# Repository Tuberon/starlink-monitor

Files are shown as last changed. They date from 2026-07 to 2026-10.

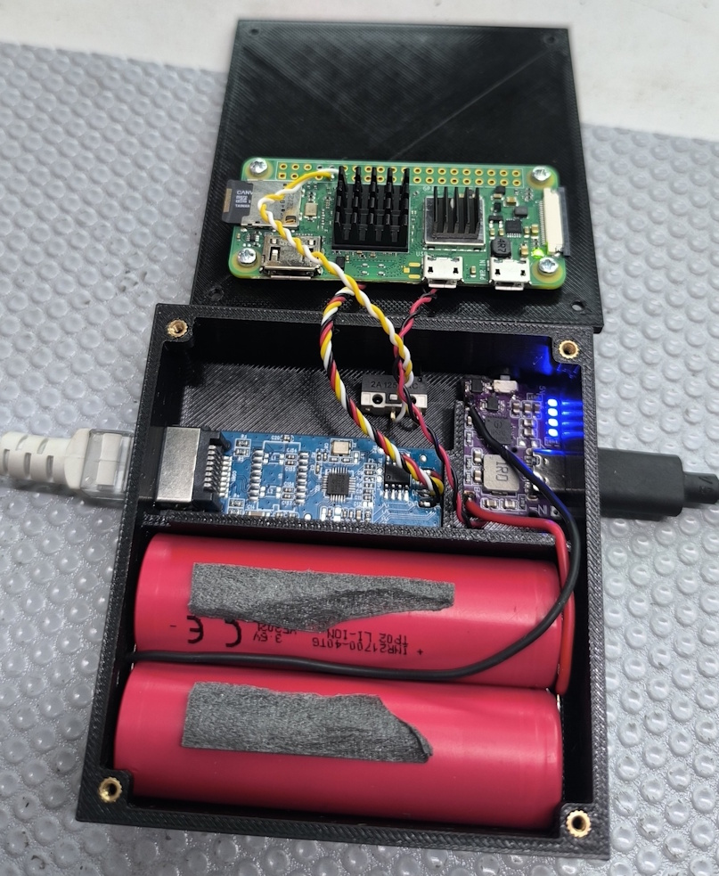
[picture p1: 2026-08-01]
dash_monitor.jpg

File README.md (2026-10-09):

# 🛰️ Starlink Mini Monitor & Watchdog — Raspberry Pi Zero 2 W

*Читати англійською: [README.en.md](README.en.md)*

Автономний монітор і watchdog для Starlink Mini на Raspberry Pi Zero 2 W.

**Зміст**: [Що робить](#-що-робить) · [Схема підключення](#-схема-підключення-опційне-обладнання) ·
[GPIO-кнопка](#-фізична-кнопка-виключення-gpio) ·
[LED активності](#-led-активності-sd-картки-gpio) ·
[TFT-дисплей](#️-фізичний-tft-дисплей-st7789-spi) ·
[Telegram](#-telegram-сповіщення-та-команди) · [Backup](#-backuprestore-налаштувань) ·
[healthz/PWA](#-додатково-healthz-pwa) · [Надійність](#️-надійність) ·
[Перевірка оновлень](#-про-ручну-перевірку-оновлень) · [Мережа](#-важливо-розуміти-про-мережу) · [Безпека](#-безпека) ·
[Навантаження](#-зниження-системного-навантаження-опційно-при-встановленні) ·
[Типізація](#-типізація-mypy) · [Тести](#-тести) ·
[Структура](#️-структура-проєкту) · [Встановлення](#-встановлення-та-оновлення) ·
[Конфігурація](#️-конфігурація) · [Залежності](#-залежності) · [Ліцензія](#-ліцензія)

## 📋 Що робить

1. Підключається до WiFi Starlink Mini як клієнт.
2. Опитує dish (`192.168.100.1:9200`, кожні 10с) і router
   (`192.168.1.1:9000`, кожні 35с) — Mini складається з ДВОХ логічних
   пристроїв в одному корпусі, кожен зі своєю прошивкою.
3. Auto-reboot усього Mini при watchdog-таймауті dish або готовому
   оновленні ПЗ (dish/router), зі спільним захистом від reboot-loop.
4. Збирає метрики Pi та історію Starlink в SQLite з автоочищенням.
5. Веб-дашборд (Flask): live-метрики, прошивки,
   WiFi-клієнти, останні 5 подій журналу, ручний reboot/перевірка
   оновлень. Сторінка `/stats` — повний журнал подій.
6. Telegram: сповіщення + команди `/status /checkupdates /reboot /id /help` (`/start` — те саме, що `/help`).
7. Reboot/shutdown Pi з веб-інтерфейсу або фізичної GPIO-кнопки,
   backup/restore всіх налаштувань одним файлом (опційно й у
   Telegram, автоматично чи вручну), `/healthz` для зовнішнього
   моніторингу, встановлюваний як PWA.
8. **Мультимовний інтерфейс** (українська/англійська) — перемикач на
   сторінці `/settings`, застосовується разом до веб-дашборду й
   Telegram-бота.

## 🔌 Схема підключення (опційне обладнання)

```
                    ┌──────────────────┐
                    │ TFT-дисплей 1.9" │
                    │ ST7789, SPI      │
                    └─────────┬────────┘
                              │ SPI: CS=GPIO8, DC=GPIO25,
                              │ RST=GPIO24, BL=GPIO18
                  ┌───────────┴───────────┐
                  │ Raspberry Pi Zero 2 W │
                  └─┬───────────────────┬─┘
           GPIO27 + │                   │ USB OTG-порт
           GND      │                   │ (єдиний, data)
           ┌────────┴────────┐  ┌───────┴───────┐
           │ Кнопка          │  │ USB-Ethernet  │
           │ вимк./підсвітка │  │ дротовий eth0 │
           └─────────────────┘  └───────────────┘

  (не показано: додатковий LED активності SD-картки — GPIO17 + GND,
   опційно, деталі нижче)
```

TFT-дисплей і кнопка — опційні (`STARLINK_DISPLAY_ENABLED=0` за
замовчуванням). USB-Ethernet теж опційний — WAN-failover fallback,
якщо є (докладніше — [Мережа](#-важливо-розуміти-про-мережу)).

## 🔘 Фізична кнопка виключення (GPIO)

Кнопка (нормально розімкнута) між обраним GPIO-піном (BCM) і GND,
внутрішній pull-up налаштовується сервісом. Увімкнено за замовчуванням
на `GPIO27` (`STARLINK_SHUTDOWN_BUTTON_PIN=27`); `0` вимикає, зміна
піна (за потреби) — у `/etc/starlink-monitor/env`:
```
STARLINK_SHUTDOWN_BUTTON_PIN=27
STARLINK_SHUTDOWN_BUTTON_HOLD_SEC=3
```
потім `sudo systemctl restart starlink-shutdown-button.service`.
Утримання довше заданого часу (типово 3с) → `systemctl poweroff`, з
подією в журналі й Telegram.

Якщо ввімкнено фізичний TFT-дисплей (`STARLINK_DISPLAY_ENABLED=1`) —
**та сама кнопка** отримує другу дію: **коротке** натискання
перемикає підсвітку дисплея, **довге** (як і раніше) вимикає Pi.
Обробляється тоді всередині `starlink-display.service`, а
`starlink-shutdown-button.service` сам себе вимикає (щоб не
конкурувати за той самий GPIO-пін). При reboot/poweroff (з кнопки чи
з веб-дашборду) — якщо дисплей увімкнено, на екрані на кілька секунд
з'являється повідомлення "Вимикається.../Перезавантажується..." перед
тим, як Pi реально почне вимикатись (`STARLINK_DISPLAY_SHUTDOWN_MESSAGE_DELAY_SEC`, типово 2с).

## 💡 LED активності SD-картки (GPIO)

Додатковий світлодіод, що коротко блимає при кожному реальному
записі в SQLite (dish-метрики, системні метрики, журнал подій,
статус router, автоматичний backup, VACUUM) — візуальна індикація
активності, аналогічна вбудованому activity-LED настільних дисків.
Вимкнено за замовчуванням (`STARLINK_ACTIVITY_LED_PIN=0`, той самий
принцип, що кнопка й дисплей — опційна периферія). Підключення: LED
(з резистором ~330Ω) між обраним GPIO-піном (BCM) і GND. Увімкнення —
у `/etc/starlink-monitor/env`:
```
STARLINK_ACTIVITY_LED_PIN=17
STARLINK_ACTIVITY_LED_BLINK_MS=50
```
потім `sudo systemctl restart starlink-monitor.service`. Обробляється
лише watchdog-процесом (не веб-дашбордом) — уникає конфлікту двох
процесів за один ексклюзивний GPIO-запит.

## 🖥️ Фізичний TFT-дисплей (ST7789, SPI)

Показує live-статус dish (online/offline, uptime, оновлення ПЗ,
версії прошивок). Вимкнено за замовчуванням (`STARLINK_DISPLAY_ENABLED=0`). Бібліотека — Adafruit CircuitPython ST7789.

> ⚠️ SPI зазвичай вимкнений: `sudo raspi-config nonint do_spi 0 &&
> sudo reboot` (`install.sh` попереджає, якщо ще не увімкнено).

Паспортна роздільна здатність — 170×320 (SKU MSP1901, portrait).
Піни залежать від підключення:
```
STARLINK_DISPLAY_ENABLED=1
STARLINK_DISPLAY_DC_PIN=25
STARLINK_DISPLAY_RST_PIN=24
STARLINK_DISPLAY_BL_PIN=18
STARLINK_DISPLAY_WIDTH=170
STARLINK_DISPLAY_HEIGHT=320
STARLINK_DISPLAY_ROTATION=0
STARLINK_DISPLAY_OFFSET_LEFT=35
```
потім `sudo systemctl restart starlink-display.service`. `BLK`
напряму до 3.3V — постав `BL_PIN=0`. `ROTATION`: `0/90/180/270`.
`OFFSET_LEFT=35` — емпіричне значення для цієї моделі (без зміщення —
кольоровий шум, підбирай кроком ~10-15px). Не міняй місцями WIDTH/HEIGHT.

Керування підсвіткою — та сама кнопка виключення (коротке=перемкнути,
довге=вимкнути Pi). Автовимкнення через `BACKLIGHT_AUTO_OFF_SEC`
(60с). При зміні статусу оновлення підсвітка блимає `UPDATE_FLASH_SEC`
(5с) — фізичне сповіщення без телефону.

## 💬 Telegram-сповіщення та команди

Налаштовуються на `/settings`:
1. Створіть бота через [@BotFather](https://t.me/BotFather), отримайте bot token.
2. Дізнайтесь chat_id через [@userinfobot](https://t.me/userinfobot).
3. Вставте token і chat_id (через кому — кілька отримувачів), "Зберегти",
   "Надіслати тестове", увімкніть перемикач.

> ⚠️ Bot token — у локальній SQLite (`settings`), у веб-інтерфейсі завжди замаскований.

**Команди** (лише для chat_id зі списку):
- `/status` — швидкий погляд: online, версія ПЗ, попередження
- `/checkupdates` — форсоване опитування dish/router, перевірка
  target-версій — та сама логіка, що кнопка на дашборді
- `/reboot` — підтвердження через inline-кнопки, 2 хв
- `/id [ID або частина]` — список тарілок або версії конкретної
- `/help` — список команд

Long polling (без webhook), у потоці `starlink-monitor.service`.

**Поведінка сповіщень:**
- `STARLINK_NOTIFY_PI_STARTUP=0` — вимикає сповіщення про реальний reboot Pi
- Тиша понад `STARLINK_NOTIFICATIONS_MUTE_AFTER` (15 хв) недоступності —
  відновлення повідомляється з тривалістю простою
- `STARLINK_NOTIFY_DISH_RECOVERY=0` — вимикає "✅ Dish знову online"
- Часті reboot групуються мовчки (`REBOOT_SPAM_THRESHOLD`/`_WINDOW_SEC`),
  підсумок після затишшя
- `STARLINK_MAX_LOGGED_FAILURES` (15) — журнал зупиняється, reboot триває
- Завжди приглушені: помилка перевірки роутера, "оновлення очікує", роумінг
- Не записуються й не показуються взагалі: попередження "карта перешкод
  скинута" (dish) і стан роутера "помилка завантаження оновлення" (тимчасова
  хмарна помилка SpaceX, роутер повторює сам)
- **Starlink вимкнено** (ніч, відключення світла): якщо не відповідає навіть
  роутер (3 опитування поспіль, ~30 с; коротші розриви WiFi ігноруються), watchdog не перезавантажує тарілку й не пише рядок на кожне
  опитування. Вранці — одне повідомлення "✅ Starlink знову доступний, був
  вимкнений N год" (лише якщо довше `NOTIFICATIONS_MUTE_AFTER`, 15 хв)
- Відкат прошивки (SpaceX інколи відкочує білди) — навмисно не
  сповіщається, `known_devices` оновлюється мовчки
- **Очікувані версії** (`/settings`) — кілька через кому, лише новіші приймаються

## 💾 Backup/restore налаштувань

На `/settings`: "Завантажити backup" — JSON з bot token, chat_id,
auto-reboot, очікуваними версіями прошивок, історією пристроїв і
перевизначеними параметрами моніторингу; "Відновити з backup" —
застосовує файл (історія пристроїв лише додається, не перезаписує наявне).

> ⚠️ Bot token у файлі — у відкритому вигляді, зберігай backup як secret.

**Відправка backup у Telegram** — автоматично періодично
(`STARLINK_TELEGRAM_BACKUP_ENABLED=1`, окремий інтервал
`_INTERVAL_HOURS`, типово тиждень) і/або вручну кнопкою "📨 Надіслати
backup у Telegram" (незалежно від автоматичного розкладу). Завжди
надсилає останній наявний файл, не створює новий — страховка на
випадок, якщо БД і backup лишаються на тій самій SD-картці.

## ➕ Додатково: healthz, PWA

- **`GET /healthz`** — для зовнішнього моніторингу (UptimeRobot тощо):
  БД доступна + watchdog реально опитує dish (свіжість метрик не старіша
  за 3 цикли опитування + інтервал пакетного запису
  `DISH_METRICS_BATCH_INTERVAL_SEC`, типово 60 с). `200 ok` / `503
  degraded`, нічого не пише в журнал — безпечно опитувати часто.
- **Встановлюваний дашборд (PWA)** — "Додати на головний екран" у
  Chrome/Edge. Service worker кешує лише статику (CSS/JS/іконки) —
  API-дані завжди наживо, service worker сам їх не кешує. Окремо:
  якщо Pi недосяжний з телефону (вийшов з WiFi-зони дії Pi) —
  дашборд показує останній відомий стан із браузерного `localStorage`
  та явним банером "останній відомий стан (X хв тому)", щоб не
  плутати із живими даними.
- **Темна/світла тема** — перемикач на `/settings`, зберігається між
  сесіями.
- **Мова інтерфейсу** — перемикач на `/settings` (українська/англійська),
  застосовується разом до веб-дашборду й Telegram-бота, включно з
  автоматичними сповіщеннями.

## 🛡️ Надійність

- **Watchdog для watchdog-а** — `starlink-monitor-healthcheck.timer`
  (раз/хв) опитує `/healthz`, примусовий restart при зависанні (не
  crash)
- **Менше записів на SD-картку** — dish-метрики batch-INSERT раз на
  `DISH_METRICS_BATCH_INTERVAL_SEC` (30с), не щоразу (зміна стану
  online/offline чи оновлення — одразу); graceful shutdown записує
  буфер перед завершенням; WAL-журнал SQLite не скидається на диск після
  кожного запису (у ~150 разів менше примусових синхронізацій), а
  налаштування синхронізуються одразу
- **ANALYZE + перевірка цілісності БД** — раз на добу (`VACUUM` — лише
  коли вільних сторінок ≥ 30%: він переписує всю БД); пошкодження →
  Telegram-сповіщення й аварійний backup
- **Автоматичний backup** — раз на тиждень, зберігає останні
  `AUTO_BACKUP_KEEP_COUNT` копій (типово 4)
- **Повторна спроба Telegram** — при мережевій помилці, `SEND_RETRIES`
- **Ротація журналу systemd** — `SystemMaxUse=200M`

## 🔄 Про ручну перевірку оновлень

Кнопка "Перевірити стан оновлень" форсує негайне локальне опитування
dish/router. Локальний gRPC API не має команди "перевір оновлення в
хмарі SpaceX" (це робить хмарний бекенд офіційного застосунку) —
`software_update` повертає `FailedPrecondition`/`Unimplemented`, тож
кнопка робить максимум технічно можливого.

## 🌐 Важливо розуміти про мережу

Starlink Mini роздає власний WiFi. RPi Zero 2 W має один WiFi-модуль,
тож для одночасного доступу до Starlink і звичайного інтернету
потрібен USB-Ethernet (рекомендовано) або лише Starlink WiFi
(моніторинг і reboot dish не залежать від зовнішнього інтернету).

При USB-Ethernet `install.sh` пропонує (лише при першому
встановленні) статичні IP для обох інтерфейсів — DHCP на обох може
спричиняти конфлікти маршрутів. На WiFi-профілі Starlink також
вимикається IPv6: коли Starlink без інтернету, системні DNS/HTTPS-
запити інакше йдуть через мертвий IPv6-маршрут замість робочого
IPv4 через `eth0`. На вже встановленій системі (мережевий блок не
повторюється при оновленні) — вручну:
`sudo nmcli connection modify "<WiFi-профіль>" ipv6.method disabled`.

**WAN-failover**: `starlink-wan-failover.timer` (~30с) перевіряє
реальний вихід в інтернет через `wlan0`; коли Starlink недоступний —
`nmcli` знижує пріоритет `wlan0`, `eth0` стає дефолтним для всієї
системи. Маршрути до dish/router не зачіпаються. Telegram-запити
мають додатковий, власний fallback (`SO_BINDTODEVICE` на `eth0` +
ручна DNS-резолюція за потреби) — працює незалежно, без
налаштування.

## 🔒 Безпека

- **Веб-інтерфейс без автентифікації** (порт `8080`,
  `STARLINK_WEBUI_HOST=0.0.0.0`) — свідоме рішення для довіреної
  локальної мережі. Не відкривайте порт в інтернет (port forwarding,
  публічні тунелі): хто бачить дашборд, може перезавантажити тарілку й
  вимкнути Pi.
- **Захист від міжсайтових запитів**: POST із чужого сайту (за
  заголовками `Origin` і `Sec-Fetch-Site`, які браузер виставляє сам)
  відхиляється з кодом 403; `curl` і скрипти без цих заголовків
  працюють. Не закрито DNS-rebinding (запит із чужого імені, що
  резолвиться в IP станції).
- **Привілеї**: сервіси працюють від непривілейованого користувача;
  `sudo` дозволяє йому рівно чотири команди (`systemctl restart` двох
  сервісів, `reboot`, `poweroff`). Лише healthcheck і WAN-failover
  працюють від root, і скрипти, які вони виконують, належать root.
- **Секрети**: токен Telegram — у `env`-файлі (права 600) і в БД
  (каталог даних 700); у логах він автоматично маскується. **Backup
  містить токен** — зберігайте його як секрет.

## 📉 Зниження системного навантаження (опційно, при встановленні)

`install.sh` (лише при першому встановленні) пропонує вимкнути
непотрібні для headless-моніторингу служби: `bluetooth`/`hciuart`,
`avahi-daemon` (mDNS), `triggerhappy`, `ModemManager` — перевіряє
кожну індивідуально (лише реально активні), вимикає (не видаляє,
легко повернути `systemctl enable --now`).

**Обережно з `avahi-daemon`**: вимикання забере доступ через
`raspberrypi.local` (не по IP) — скрипт попереджає, якщо активна.

Мережеві служби (`ssh`, `NetworkManager`, `dhcpcd`) ніколи не
пропонуються — headless-пристрій без фізичного доступу не можна
ризикувати заблокувати від SSH. Окремо — `apt-get autoremove`/`clean`.

Натомість `install.sh` вмикає `fstrim.timer` (періодичний TRIM для
SD-картки; якщо картка його не підтримує — нічого не робить, не
шкодить).

## 🔍 Типізація (mypy)

Увесь код проєкту (крім `app/vendor/` — сторонній код) типізований і
проходить `mypy` у **суворому режимі** (`app/*` — еквівалент `--strict`,
прапорці в `mypy.ini`; у `tests/` типізація м'яка). Виклики `requests`,
`psutil`, `dns` перевіряються справжніми стабами (`types-*` у
`requirements-dev.txt`); ігнорування імпортів дозволено лише для
апаратних бібліотек Pi — суворість тримає тест
`test_mypy_config_stays_strict`. Результат `mypy` залежить від
встановлених пакетів (без Flask — понад 30 помилок, усі в `webapp.py`),
тож запускати у повному dev-середовищі. Перевірка перед
комітом/оновленням:
```bash
pip install -r requirements-dev.txt
mypy app/
ruff check .
```
`ruff check` — перевірка коду (невикористане, типові пастки, безпека;
правила в `ruff.toml`), також виконується як один із тестів. Не
автоформатування: `ruff format` свідомо не використовується. Без CI — для одноосібного hobby-проєкту такого
масштабу пропорційніше запускати локально як ще одну живу перевірку
поруч із `py_compile`, ніж інвестувати в повноцінну CI-інфраструктуру
(деталі рішення — `docs/decisions-log.md`).

## ✅ Тести

1116 тестів (`pytest-randomly` — стійкість до порядку виконання), 27
файли у `tests/`. Крім stateful-логіки (групування reboot-спаму,
дедублікація сповіщень про target-версії прошивки, компаратор версій,
eth0-fallback для Telegram) — і hardware-залежний код (GPIO/SPI-
дисплей, кнопка виключення) тестується підміною `sys.modules` для
`gpiod`/`board`/`digitalio`/`busio`/`adafruit_rgb_display` ще до
виклику функції (ці бібліотеки самі імпортуються лише всередині
функцій, не на рівні модуля). Кожен тест автоматично отримує
тимчасові БД, файл налаштувань і теку бекапів (`tests/conftest.py`) —
робочих `/etc/starlink-monitor` і `/var/lib/starlink-monitor` тести не
торкаються. Перевірка (на машині розробки):
```bash
pip install -r requirements.txt -r requirements-dev.txt
pytest
```
Покриття по модулях: `pytest --cov=app --cov-report=term-missing`.

Тести власності root (`test_install_security.py`) виконуються лише від
root і пропускаються для звичайного користувача.

**На самому Pi** — в окремому середовищі (не в робочому `/opt/.../venv`,
без `--break-system-packages`) і без бібліотек заліза (`adafruit-*`), щоб
жоден тест не торкнувся справжніх GPIO/SPI. Сервіси можуть працювати:
```bash
cd ~/starlink-monitor            # розпакований архів
python3 -m venv ~/dw-dev
grep -vi adafruit requirements.txt > /tmp/req-tests.txt
~/dw-dev/bin/pip install -r /tmp/req-tests.txt -r requirements-dev.txt
~/dw-dev/bin/mypy app/ && ~/dw-dev/bin/ruff check . && ~/dw-dev/bin/pytest
```

## 🗂️ Структура проєкту

```
starlink-monitor/
├── app/            # Python: моніторинг, Flask, Telegram, GPIO, дисплей, i18n
├── templates/      # HTML (index, settings, stats)
├── static/         # JS/CSS/іконки
├── tests/          # 1116 тестів (27 файлів), pytest-randomly
├── systemd/        # unit-файли сервісів
├── scripts/        # install/update/uninstall + системні перевірки
├── docs/           # architecture.md, index.md (повний опис кожного файлу), decisions-log.md, plan.md
├── requirements.txt      # production-залежності (прямі, точні піни)
├── constraints.txt       # закріплені ТРАНЗИТИВНІ версії (pip install -c)
├── requirements-dev.txt  # mypy/pytest/ruff/pip-audit/hypothesis
├── mypy.ini              # mypy: суворий режим для app/*
├── pytest.ini            # налаштування pytest
├── ruff.toml             # ruff: правила F, B, E9, PLE, S
└── LICENSE               # MIT
```

Детальний опис кожного файлу — [`docs/index.md`](docs/index.md).

## 📦 Встановлення та оновлення

**📥 Перше встановлення:**
```bash
tar -xzf starlink-monitor.tar.gz && cd starlink-monitor
sudo bash scripts/install.sh
```
Ставить системні пакети, `grpcurl`, Python venv, sudo-права,
systemd-сервіси; наприкінці — опційний запит статичних IP і опційне
вимкнення непотрібних для headless-моніторингу системних служб
(лише при першому встановленні, див. секції вище — "Важливо
розуміти про мережу" й "Зниження системного навантаження").

**🔁 Оновлення** (архів у домашньому каталозі, напр. через `scp`):
```bash
sudo bash /opt/starlink-monitor/scripts/update.sh
```
Розпаковує й викликає `install.sh` в update-режимі: системні пакети
не чіпаються, синхронізуються лише змінені файли, мережевий запит не
повторюється. SHA-256 запобігає повторному встановленню того самого
архіву; шлях можна вказати аргументом.

Після установки каталог `/opt/starlink-monitor` і `scripts/` належать
root: їх виконує root (юніти healthcheck і WAN-failover та `update.sh`
під `sudo`), тож непривілейований користувач сервісів не може їх
підмінити. Редагувати їх вручну — через `sudo`; `app/` і `venv`
лишаються за користувачем сервісів.

**✅ Після встановлення:**
1. `sudo nmcli device wifi connect "<SSID>" password "<пароль>" ifname wlan0`
2. Дашборд: `http://<ip-пристрою>:8080`

**🗑️ Повне видалення:**
```bash
sudo bash /opt/starlink-monitor/scripts/uninstall.sh
```
Зупиняє сервіси, видаляє код і sudoers-правило. Історію метрик і
Telegram-налаштування видаляє лише після окремого підтвердження — за
замовчуванням лишаються для повторного встановлення.

## ⚙️ Конфігурація

Редагується на сторінці `/settings` (панель "Параметри моніторингу",
53 параметри згруповані за категоріями: моніторинг/надійність/
Telegram/GPIO) або вручну в `/etc/starlink-monitor/env`. Повний
список з коментарями — у `app/config.py`.

3 параметри навмисно недоступні через `/settings` (лише ручне
редагування `.env`-файлу) — `STARLINK_DB_PATH` (зміна шляху до БД
без міграції даних), `STARLINK_WEBUI_HOST` (self-lockout — можна
відрізати себе від `/settings`, змінивши адресу прослуховування) і
`STARLINK_AUTO_BACKUP_DIR` (дефолт обчислюється поруч із БД).

`/settings` перевіряє не лише тип, а й допустимий діапазон кожного числового
параметра: відхиляє `nan`/`inf`, від'ємні значення та `0` для таймерів (там `0`
означав би «на кожній ітерації», а не «вимкнено»); нуль лишено лише там, де він
справді означає «вимкнено» (піни, автовимкнення підсвітки). Адреси `STARLINK_DISH_ADDR`/`STARLINK_ROUTER_ADDR` приймаються лише як
`host:порт` (порт 1–65535). Ручне редагування `env`-файлу межі не перевіряє, але й не валить сервіси: некоректне значення (порожнє, `abc`) замінюється типовим із попередженням у журналі; булеві приймають `1/true/yes/on` і `0/false/no/off`.

Найважливіші для першого налаштування:

| Змінна | За замовчуванням | Опис |
|---|---|---|
| `STARLINK_DISH_ADDR` | `192.168.100.1:9200` | адреса тарілки |
| `STARLINK_ROUTER_ADDR` | `192.168.1.1:9000` | адреса роутерного компонента Mini |
| `STARLINK_WEBUI_PORT` | `8080` | порт веб-інтерфейсу |
| `STARLINK_HISTORY_DAYS` | `14` | скільки днів зберігати історію метрик/подій |
| `STARLINK_MAX_FAILURES` | `6` | скільки невдалих опитувань перед watchdog-reboot |

GPIO-піни опційних фіч (кнопка/LED/дисплей) — див. відповідні секції
вище, кожна опційна фіча описана окремо з power-схемою.

Параметри читаються один раз при старті процесів — після збереження
на `/settings` натисни "Зберегти й перезапустити сервіси" (кнопка
поруч), або вручну:
```bash
sudo systemctl restart starlink-monitor.service starlink-webui.service
```

## 🧩 Залежності

`requirements.txt` закріплює прямі пакети, `constraints.txt` —
транзитивні (`install.sh` ставить `pip install -r requirements.txt -c
constraints.txt`; без цього pip ніколи не оновлював уже встановлені,
зокрема системні, версії). Апаратні `adafruit-*` свідомо не закріплені.
Аудит вразливостей: `pip install pip-audit && scripts/audit_deps.sh`.

**Vendored `starlink_grpc.py`.** Походження зафіксовано в
`app/vendor/PROVENANCE` (upstream-коміт, дата, sha256; тест звіряє їх з
файлом). Оновлення до найновішої upstream-версії — опційно,
`scripts/fetch_starlink_grpc.sh` (завантаження у тимчасовий файл,
перевірки, резервна копія `.prev`, атомарна заміна; `--commit=<sha>` —
конкретна ревізія; `--wait-for-dish` — чекати доступності тарілки;
`--restart-services` — перезапустити сервіси після успіху).

## 📄 Ліцензія

© 2026 JunioR. Розповсюджується під ліцензією MIT — див. файл
[`LICENSE`](./LICENSE).

Проєкт включає (vendored, `app/vendor/starlink_grpc.py`) файл зі
стороннього репозиторію
[sparky8512/starlink-grpc-tools](https://github.com/sparky8512/starlink-grpc-tools)
для відтворюваності збірки (не завантажується динамічно при
встановленні) — **його ліцензійні умови визначає власний автор**, окремо
від MIT цього репозиторію (Unlicense — суспільне надбання). Походження й
оновлення — у розділі «Залежності».

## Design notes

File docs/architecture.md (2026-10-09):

# Архітектура: Starlink Mini Monitor & Watchdog

## Призначення

Моніторинг і автоматичне обслуговування Starlink Mini через Raspberry
Pi Zero 2 W: веб-дашборд, watchdog з авто-reboot, Telegram-сповіщення
й вхідні команди.

## Фізична топологія

Starlink Mini = **два логічні пристрої в одному корпусі**, кожен зі
своєю прошивкою:
- **dish** (тарілка): `192.168.100.1:9200`, gRPC через `starlink_grpc.py`
- **router** (WiFi-роутер): `192.168.1.1:9000`, gRPC через `grpcurl` subprocess

Це підтверджено живими викликами (`grpcurl describe`) під час
розробки — обидва мають окремі `DeviceInfo`, окремі стани оновлення
ПЗ (`SoftwareUpdateState` для dish, `WifiSoftwareUpdateState` для
router — різні enum з різними назвами станів).

## Модулі (app/)

| Файл | Відповідальність |
|---|---|
| `starlink_client.py` | gRPC-клієнт: статус dish/router, reboot_dish(); vendored gRPC-стек вантажиться ліниво (`_grpc_module()`) |
| `monitor.py` | Watchdog: цикл опитування (періодичні задачі `_Periodic`), авто-reboot, логування подій, запуск Telegram-бота (точка входу) |
| `services.py` | Спільна логіка для monitor/webapp/telegram_bot: відстеження версій прошивок (`check_updates_now`, `upsert_*`), бекапи (`perform_auto_backup` з ротацією), перевірка цілісності БД |
| `webapp.py` | Flask, REST API (довідник нижче), роздає `/`, `/settings`, `/stats`, `/healthz`; відхиляє POST із чужого сайту (CSRF), у JSON немає `Infinity`/`NaN` |
| `db.py` | SQLite: metrics, events, system_metrics, router_status, known_devices, settings; атомарні "прочитати → вирішити → записати" (`claim_setting`, `BEGIN IMMEDIATE`), "останній" запис ігнорує рядки з майбутнього |
| `i18n.py` | Мультимовний інтерфейс (uk/en): словник перекладів, `t()`, мова з settings |
| `telegram_notify.py` | Вихідні сповіщення (повторна спроба, eth0-fallback; токен не потрапляє в логи) |
| `log_redact.py` | Маскування токена бота в текстах помилок і логах (`redact()`, `RedactingFilter`) |
| `telegram_bot.py` | Вхідні команди `/status`, `/checkupdates`, `/reboot`, `/id`, `/help` (`/start` = `/help`); обробка кожного update у пулі потоків, не блокує polling |
| `atomic_io.py` | Атомарний запис файлів (temp → fsync → replace): env зі /settings і автобекапи не обнуляються до запису |
| `labels.py` | Спільні таблиці "код -> ключ перекладу" для станів оновлення й alert-прапорців (monitor.py + telegram_bot.py, без дублювання; `_label()` перекладає лише потрібний код) |
| `system_metrics.py` | Метрики Pi (CPU/RAM/диск/температура) |
| `shutdown_button.py` | Фізична кнопка виключення через GPIO (окремий процес) |
| `pi_power.py` | Спільний reboot/poweroff для webapp.py/shutdown_button.py, DB-сигнал для повідомлення на дисплеї |
| `activity_led.py` | Опційний LED активності SD-картки - блимає при кожному commit у БД (не окремий процес, частина monitor.py) |
| `display.py` | Фізичний TFT-дисплей статусу (ST7789, SPI, окремий процес) |
| `gpio_utils.py` | Спільна gpiod v1/v2-сумісна логіка читання GPIO-входу (shutdown_button.py + display.py) і запису GPIO-виходу (activity_led.py) |
| `config.py` | Конфігурація, env-змінні |
| `config_editor.py` | Читання, валідація (таблиця `_VALIDATORS`, межі `LIMITS`, формат адрес) і атомарний запис `/etc/starlink-monitor/env` через `/settings` |

`app/vendor/starlink_grpc.py` — **vendored** (фізично включений в архів
проєкту, не в таблиці вище, бо не наш код) файл зі стороннього
репозиторію sparky8512/starlink-grpc-tools, для відтворюваності
збірки: install.sh НЕ завантажує його динамічно з інтернету; `starlink-grpc-fetch.service` встановлюється, але НЕ вмикається автоматично (опційне ручне оновлення до найновішої upstream-версії).
`starlink_client.py` вантажить його ЛЕДАЧЕ — `_grpc_module()` при
першому зверненні до тарілки (не при імпорті модуля): gRPC + protobuf +
`yagrc` + vendored файл — це ~13 МБ RSS і ~50 мс, а веб-процес імпортує
клієнта лише заради двох кнопок. Імпорт іде через `from app.vendor
import starlink_grpc` у `try/except Exception` (не лише ImportError:
обірваний файл дає `SyntaxError`, відсутній `yagrc` —
`ModuleNotFoundError`), під блокуванням (потоки монітора,
бота й веб-запитів не імпортують і не логують помилку кожен окремо).
Недоступний модуль → `starlink_grpc = None`, а `get_status()` віддає
`DishStatus(online=False, local_fault=True, error="starlink_grpc module
missing (<причина>)")`. Тести підміняють глобальну `starlink_grpc`
напряму; початкове значення — маркер `_UNLOADED`.

**`local_fault`** — помилка НАШОЇ сторони, не тарілки. Без цієї позначки
watchdog вважав тарілку зависшою й перезавантажував її кожні
`MIN_REBOOT_INTERVAL` (симуляція: 22 рази за 67 хв) — тобто пошкоджений
локальний файл відключав би інтернет; колишній опис "код і далі коректно
працює" був неправдою. Тепер `poll_once()` при `local_fault` не рахує збій, не
перезавантажує тарілку й повідомляє РАЗ за процес (подія `local_fault`, лог,
Telegram); усунення потребує відновлення файлу й перезапуску сервісу (модуль
завантажується при старті).

**Походження й оновлення.** `app/vendor/PROVENANCE` фіксує upstream-коміт
(зараз `8f34f4cd…`, 2026-03-20; знайдено порівнянням sha256 з усією історією
файлу — збіг побайтовий), дату, sha256 і ліцензію (Unlicense); тест звіряє
sha256 із файлом. `scripts/fetch_starlink_grpc.sh` тепер: завантаження у
тимчасовий файл → перевірки (розмір ≥ 20 КБ, синтаксис Python, наявність
`ChannelContext` і `get_status` — те, що використовує наш клієнт) →
резервна копія `starlink_grpc.py.prev` → атомарна заміна → запис
`PROVENANCE`. Завантаження — за незмінним URL з SHA коміту (з Atom-стрічки
комітів; `--commit=<sha>` задає ревізію явно), а не з рухомої гілки `main`.

**Залежності.** `requirements.txt` — прямі точні піни, `constraints.txt` —
закріплені транзитивні (12 пакетів, складено у чистому venv; урахований
`grpcio-reflection` від `yagrc`). `install.sh` ставить `pip install -r
requirements.txt -c constraints.txt` і вважає залежності зміненими, якщо
різняться requirements.txt АБО constraints.txt. Constraints лише обмежують
версії й не додають імен, тому не викликають "суттєвої зміни" (повного
перевстановлення); апаратні `adafruit-*` не зачіпаються. Причина: `pip`
вважає вже встановлені (зокрема системні, через `--system-site-packages`)
версії задоволеними, тож на Pi транзитивні пакети (urllib3 2.6.3, idna 3.11
з advisory) не оновлювались ніколи. Аудит: `scripts/audit_deps.sh`.

## Автоматичний reboot dish/router — умови спрацювання

1. **Watchdog**: dish не відповідає N опитувань поспіль
2. **Update-ready dish**: `update_state == "REBOOT_REQUIRED"`
3. **Update-ready router**: `update_state == "REBOOT_PENDING"`

Усі три через `db.get_auto_reboot_enabled()` (runtime, перемикається
з веб-інтерфейсу без перезапуску сервісу) і захищені
`MIN_REBOOT_INTERVAL_SEC` (180с) від reboot-loop.

`Watchdog.first_failure_ts` відслідковує тривалість безперервної
недоступності dish. Якщо вона перевищує `NOTIFICATIONS_MUTE_AFTER_SEC`
(900с) — Telegram-сповіщення про watchdog auto-reboot придушуються
(`db.insert_event` не зачіпається, лише `_notify`); відновлення
зв'язку повідомляється (`✅ Dish знову online...`), якщо
`NOTIFY_DISH_RECOVERY=1` (дефолт, `0` вимикає — journal-лог
(`logger.info`) і далі пишеться незалежно від цього параметра,
лише Telegram-сповіщення пригнічується; знайдено запитом
користувача — короткі flap-відновлення не завжди інформативні).

**Starlink вимкнено** (`_enter_starlink_offline()`/`_exit_starlink_offline()`): коли dish не відповідає, `poll_once()` перевіряє TCP-
з'єднання з gRPC-портом роутера (`StarlinkClient.router_reachable()`,
2 с; без WiFi Starlink пакети йдуть маршрутом за замовчуванням через
eth0 і чекають повний timeout). Роутер
теж мовчить — це вимкнений Starlink (ніч, відключення світла), а не
зависання тарілки: reboot не шлеться (команда йде тим самим
недоступним шляхом), `consecutive_failures` не росте, рядок на кожне
опитування не пишеться — лише подія `starlink_offline` на вхід і
`starlink_online` на вихід. Telegram — одне повідомлення при поверненні,
якщо Starlink був вимкнений довше `NOTIFICATIONS_MUTE_AFTER_SEC`
(хвилинні перезавантаження при оновленні прошивки мовчать — вони мають
власні сповіщення). Роутер відповідає, dish ні — звичайний watchdog.
Виявлено на реальній ночі користувача: 9+ год вимкненого Starlink
давали ~114 марних спроб reboot і ~5900 рядків журналу. `"Пропускаю
авто-reboot"` пишеться один раз на вікно очікування
(`_reboot_skip_logged_for`), не щоопитування. Гістерезис: стан
фіксується, лише коли роутер мовчить `STARLINK_OFFLINE_CONFIRM_POLLS`
(3) опитувань поспіль; тривалість рахується від першого збою. Без
цього щохвилинні пів-секундні розриви WiFi на Pi користувача, що
інколи збігаються з опитуванням, давали до ~100 подій на годину.

**Групування reboot-спаму** (`_notify_reboot()`/`_check_reboot_spam_recovery()`) — інша ситуація, ніж `NOTIFICATIONS_MUTE_AFTER_SEC`: та
працює за ТРИВАЛІСТЮ однієї безперервної відмови, це — за ЧАСТОТОЮ
окремих коротких reboot-циклів (флап), кожен з яких минає
`MIN_REBOOT_INTERVAL_SEC` і тому НЕ приглушується першим механізмом.
`Watchdog.reboot_notify_ts` — ковзний список timestamps уже
надісланих reboot-сповіщень (не всіх спроб reboot, лише тих, що
дійшли до Telegram); коли їх назбирається `REBOOT_SPAM_THRESHOLD`+ за
`REBOOT_SPAM_WINDOW_SEC` — подальші мовчки рахуються (`muted_reboot_count`), **без окремого повідомлення про початок групування** (щоб
не додавати ще одне сповіщення до вже частих — навмисно прибрано за
запитом користувача), до затишшя (`_check_reboot_spam_recovery()`,
викликається щоцикл на початку `poll_once()`), тоді підсумок і
повний скид стану. Застосовано лише до **успішних** reboot-
сповіщень (`🔁`) — невдалі (`❌`) лишаються без групування, рідкісніші
й важливіші показувати щоразу.

## systemd-сервіси

| Сервіс | Роль | Особливості безпеки |
|---|---|---|
| `starlink-monitor.service` | Watchdog + Telegram-бот (потік) | `NoNewPrivileges=true`, `AmbientCapabilities=CAP_NET_RAW` (SO_BINDTODEVICE), `CapabilityBoundingSet` звужено до цієї capability |
| `starlink-webui.service` | Flask dashboard | БЕЗ `NoNewPrivileges` (потрібен sudo для reboot/poweroff Pi), `AmbientCapabilities=CAP_NET_RAW`, `CapabilityBoundingSet` НЕ звужено (sudo systemctl reboot успадкував би обмеження) |
| `starlink-shutdown-button.service` | Слухає GPIO-кнопку виключення | БЕЗ `NoNewPrivileges` (sudo poweroff), `Restart=on-failure` (не `always` — чистий вихід при вимкненій кнопці не збій) |
| `starlink-grpc-fetch.service` | Опційне ручне оновлення vendored `starlink_grpc.py` до найновішої upstream-версії — НЕ enabled/started автоматично (файл vendored, `app/vendor/`) | — |
| `starlink-wan-failover.service`/`.timer` | Періодична (кожні ~30с) перевірка інтернету через wlan0, коригування route-metric | root-сервіс; `CapabilityBoundingSet=CAP_NET_ADMIN CAP_NET_RAW` — навіть root тут без решти системних можливостей |
| `starlink-monitor-healthcheck.service`/`.timer` | Раз/хв опитує `/healthz`, force-restart `starlink-monitor.service` при не-200 (deadlock/livelock, не crash — `Restart=always` цього не бачить) | root-сервіс (потрібен для `systemctl restart` іншого юніта); `NoNewPrivileges=true`, `ProtectSystem=strict` |
| `starlink-display.service` | Фізичний TFT-дисплей (ST7789, SPI), вимкнено за замовчуванням | `SupplementaryGroups=gpio spi`; БЕЗ `NoNewPrivileges` (кнопка виключення обробляється тут же, потребує `sudo poweroff` — реальний баг був знайдений і виправлений: старий коментар помилково лишав `NoNewPrivileges=true` вже після того, як обробку кнопки перенесли сюди) |

`ProtectSystem=strict` на всіх — файлова система read-only, крім явно
дозволених шляхів.

## Встановлення / оновлення

- `scripts/install.sh` — детектує install vs update режим
  (`/opt/starlink-monitor` існує чи ні). У update-режимі: пропускає
  apt/pip якщо `requirements.txt` не змінився; **виявляє суттєві
  зміни** (нові пакети — не просто зміна версії) і при виявленні
  повністю видаляє й перевстановлює. Наприкінці, **лише в install-режимі** —
  опційний інтерактивний блок налаштування статичних IP для eth0/wlan0
  (з підтвердженням, дефолти редаговані), вимикає конфліктуючий `dhcpcd`.

  **Зниження системного навантаження** (теж лише install-режим, після
  мережевого блоку) — інтерактивна пропозиція `systemctl disable --now`
  для короткого, добре перевіреного списку служб (`bluetooth`,
  `hciuart`, `avahi-daemon`(+`.socket`), `triggerhappy`, `ModemManager`).
  Кожен кандидат перевіряється **індивідуально** через `systemctl
  list-unit-files`+`is-enabled`/`is-active` **перед** пропозицією — не
  питає про службу, якої немає в системі (мінімальні образи вже можуть
  бракувати частини списку). **Вимикає, не видаляє** пакети — уникає
  ризику зламаних залежностей через `apt purge`, легко відновлюється
  через `systemctl enable --now`. Явне попередження про `avahi-daemon`
  (`.local`-mDNS-резолюція), якщо він серед виявлених кандидатів —
  вимкнення могло б забрати доступ через `raspberrypi.local` для тих,
  хто підключається так, не по IP. Мережеві служби (`ssh`,
  `NetworkManager`, `wpa_supplicant`, `dhcpcd`) і core systemd-юніти
  **ніколи не входять у список кандидатів** — на headless-пристрої без
  фізичного доступу заблокований SSH означає повну втрату контролю.
  Окремий, незалежний крок (той самий блок) — опційний `apt-get
  autoremove`/`clean` (дисковий простір, не RAM/CPU).
- `scripts/update.sh` — ручне оновлення: sha256-перевірка архіву,
  розпакування, виклик install.sh.
- `scripts/uninstall.sh` — зупиняє й видаляє сервіси, sudoers-правило,
  код (`/opt/starlink-monitor`). БД (`/var/lib/starlink-monitor`) і
  env-конфіг (`/etc/starlink-monitor`) видаляються лише після окремого
  підтвердження — за замовчуванням лишаються для повторного встановлення.

## База даних (SQLite, /var/lib/starlink-monitor/history.db)

WAL journal_mode — паралельне читання (webui) і запис (monitor) без блокувань.
`synchronous=NORMAL` (не дефолтний `FULL`) — офіційно рекомендований
режим для WAL: `fsync()` лише при checkpoint, не на кожному commit,
суттєво менше фізичних записів на SD-картку при опитуванні кожні
~10с. Ризик — втрата лише кількох останніх транзакцій при раптовому
знеструмленні (БД не пошкоджується, це гарантує WAL сам по собі).

- `metrics` — історія опитувань dish (latency, dish_id, update_state, ...)
- `events` — журнал подій (reboot, зміни стану, попередження, підключення
  нової тарілки). Повтори того самого `kind`+`message` підряд стискаються
  в один рядок (`count` замість нового запису щоразу)
- `system_metrics` — CPU/RAM/диск/температура Pi
- `router_status` — останній відомий стан роутера, включно зі списком
  під'єднаних WiFi-клієнтів (`clients`: ім'я/MAC, IP, діапазон, сигнал,
  час у мережі)
- `settings` — runtime key-value (auto_reboot_enabled, telegram config,
  dish_target_version/router_target_version + їхні
  `*_notified` пари — див. нижче)

**Write-only колонки, залишені в схемі без запису** (аудит показав, що
ніколи не читаються: `metrics.currently_obstructed` дублює
`obstruction_fraction`, `router_status.bootcount` ніколи не
відображався, `events.last_ts` дублював `ts` в одному й тому самому
UPDATE): значення `NULL` для нових рядків, старі рядки не чіпались;
`starlink_client` ці два поля відповіді Starlink більше й не розбирає.
Схема НЕ змінена (без `DROP COLUMN`) — менший ризик для вже існуючих БД
на реальних пристроях, ніж міграція.
- `known_devices` — по одному рядку на dish_id: версії ПЗ dish/router
  і час останньої зміни кожної. Джерело для `/id <dish_id>` у Telegram-боті.
  `upsert_known_device_dish()`/`upsert_known_device_router()` повертають
  `(real_change, old_version)` — `real_change=True` лише коли версія
  реально відрізняється від РАНІШЕ ВІДОМОГО значення (не `None`, не
  перше знайомство з пристроєм/полем), і завжди оновлюють `known_devices` реальною поточною версією незалежно від напрямку зміни.
  `services.upsert_dish_and_notify()`/`upsert_router_and_notify()`
  сповіщають лише про реальне ОНОВЛЕННЯ (`format_firmware_change_message()`,
  використовує `db.is_older_version()` — той самий
  толерантний компаратор, що для target-версій): "🔄 Прошивка X
  оновлена: X → Y" для forward-змін. Якщо нова версія СТАРІША за
  попередню (SpaceX інколи відкочує прошивку глобально) - навмисно
  НЕ сповіщає (`format_firmware_change_message()` повертає `None`,
  обидва виклики перевіряють на `None` перед `notify_fn(...)`) - за
  запитом користувача, `known_devices` все одно оновлюється мовчки.
  Спільний для dish і router (та сама функція).

`Watchdog._log_alerts_change()` журналює появу/зникнення кожного dish-
alert'а окремою подією в БД (`dish_alert`/`dish_alert_resolved`).
Виняток: `obstruction_map_reset` при ЗНИКНЕННІ (`resolved`) навмисно
пропускається повністю — Starlink періодично скидає карту перешкод
сам по собі як частину нормальної роботи (не аварійна подія), тому
"Попередження знято: карта перешкод скинута" не журналюється взагалі.
Точковий фільтр лише для цього одного alert'а й лише для `resolved`-
напрямку — при появі (`appeared`) той самий alert усе ще журналюється
й потрапляє в Telegram (не в `MUTED_DISH_ALERTS`), лише завершення
цього конкретного, нормального циклу не варте окремого запису.

**"🟢 Dish Watch запущено (Raspberry Pi перезавантажено)"** —
`monitor.pi_just_booted()` (чиста, тестована функція, порівнює
`psutil.boot_time()` з `time.time()`, поріг 120с) відрізняє РЕАЛЬНЕ
завантаження Pi від звичайного `sudo systemctl restart starlink-monitor.service` (напр. під час `update.sh`) — без цього сповіщало б
набагато частіше, ніж "Pi увімкнувся/перезавантажився". Викликається
на початку `run_forever()`, одразу після `db.init_db()`, ПЕРЕД
`telegram_bot.start()` (не залежить від нього — `telegram_notify.send_message()` окремий, самостійний модуль). `NOTIFY_PI_STARTUP=0`
(дефолт `1`) вимикає повністю.

## Буферизація dish-метрик (SD-card-wear reduction)

`Watchdog.metrics_buffer` — dish-зчитування (кожні `POLL_INTERVAL_SEC`,
типово 10с) накопичуються в пам'яті замість негайного окремого
запису. `flush_metrics_buffer()` викликає `db.insert_metrics_batch()`
(одна транзакція, `executemany`) раз на `DISH_METRICS_BATCH_INTERVAL_SEC` (типово 30с) — зменшує кількість фізичних write-транзакцій на
SD-картку **в рази**, без втрати жодної точки даних (усі зчитування
все одно потрапляють у БД, лише трохи пізніше).

**Зміна стану — одразу.** Дашборд і TFT-дисплей читають БД, тож без
цього новий стан (online/offline, стан оновлення прошивки; на станції —
заміна Starlink) з'являвся там із затримкою до 30 с. `poll_once()`
скидає буфер, щойно `(online, update_state)` відрізняється від
попереднього опитування; однакові опитування — пакетом, як і раніше.
`flush_metrics_buffer()` **ніколи не кидає виняток** (викликається з
трьох місць: періодично в циклі, при зміні стану й з обробника SIGTERM):
при недоступній БД (заблокована, повна SD) збій лише логується, буфер
лишається в пам'яті (стеля `_METRICS_BUFFER_MAX` = 8640 записів, ~доба;
понад це відкидаються найстаріші), повтор — через
`DISH_METRICS_BATCH_INTERVAL_SEC`. Раніше виняток із періодичного
виклику валив увесь процес монітора — зависла тарілка не
перезавантажувалась, поки БД недоступна.

**"Якір" WAL** (`db.open_anchor()` у `run_forever()`) — одне незадіяне
з'єднання на весь час роботи монітора. Без нього WAL фактично не діяв:
кожна операція відкриває й закриває з'єднання, а закриття ОСТАННЬОГО
змушує SQLite зробити повний checkpoint і видалити `-wal` — кожен запис
проходив "WAL → fsync → копія в БД → fsync → видалення WAL". З якорем
checkpoint відбувається лише за `wal_autocheckpoint` (1000 сторінок).
Вимір на коді проєкту: fdatasync −99%, видалень WAL −99.5%, обсяг
записів −49%. Компроміс: з `synchronous=NORMAL` звичайні записи
потрапляють на SD протягом ~30 с (скидання буферів ядра); при раптовому
вимкненні — втрата останніх ~30 с метрик, без пошкодження БД (контрольні
суми WAL). Налаштування й історія пристроїв (`set_setting`,
`_upsert_known_device`, `merge_known_devices`) — `get_conn(durable=True)`,
`synchronous=FULL`: синхронізуються одразу. При зупинці сервісу якір
закривається в `finally` — штатний checkpoint, `-wal` видаляється.

**Graceful shutdown** — без цього звичайний `sudo systemctl restart`
(наприклад, під час `update.sh`) втрачав би до `DISH_METRICS_BATCH_INTERVAL_SEC` буферизованих даних щоразу, не лише при справжньому
раптовому вимкненні живлення (для якого ця втрата — свідомо прийнятий
компроміс, не помилка). `run_forever()` реєструє обробники `SIGTERM`/
`SIGINT`, які викликають `flush_metrics_buffer()` перед виходом
(`raise SystemExit(0)`).

**`/healthz`** — поріг свіжості (`webapp.py healthz()`) враховує
можливу batch-затримку: `max_age_sec = POLL_INTERVAL_SEC * 3 +
DISH_METRICS_BATCH_INTERVAL_SEC` — знайдено ДО реалізації буферизації
(не постфактум): без цього додавання сама буферизація хибно
спрацьовувала б як "watchdog завис", оскільки старий поріг (30с)
точно збігався з новим batch-інтервалом.

**Другорядний ефект, свідомо прийнятий**: `check_both_targets_reached()` читає `db.get_latest_metric()` для комбінованого "🎉
обидва" сповіщення — це значення може відставати на до `DISH_METRICS_BATCH_INTERVAL_SEC`. Головне, per-component сповіщення
(`check_target_version_reached()` через `upsert_dish_and_notify()`)
використовує live `DishStatus`-об'єкт напряму, не БД — працює без
жодної затримки.

**`db._metric_row_params()`** — спільний helper для формування
tuple параметрів INSERT, використовується і `insert_metric()`
(один рядок, ручна перевірка через `check_updates_now()` — навмисно
НЕ буферизується, користувач очікує негайного запису й відповіді),
і `insert_metrics_batch()` (`executemany` для кількох рядків) —
уникає дублювання SQL-запиту.

**`SYSTEM_METRICS_INTERVAL_SEC`** (типово 60с) — CPU/температура/
пам'ять Pi змінюються повільно, записувати їх із тією самою
частотою, що критичні dish-метрики (10с), зайве навантаження без
практичної користі. Окрема періодична задача циклу (`_Periodic`), той самий
паттерн, що вже для router нижче.

## Надійність: integrity-check, автоматичний backup, Telegram-retry

**`db.check_integrity()`** (`PRAGMA quick_check`) — той самий
щоденний цикл, що `vacuum_and_analyze()`. Ловить `sqlite3.DatabaseError` окремо (файл ВЗАГАЛІ не SQLite, не лише пошкоджені
дані всередині — `PRAGMA quick_check` сам кидає виняток у цьому
крайньому випадку, знайдено живим тестом). `services.check_db_integrity_and_notify()` при пошкодженні — Telegram-сповіщення +
спроба аварійного `perform_auto_backup()` (в `try/except` — backup
теж може провалитись, читаючи з тієї самої пошкодженої БД).

**`services.build_backup_dict()`** — спільна для `webapp.py api_settings_backup()` (ручний, веб-кнопка) і `perform_auto_backup()`
(автоматичний, періодичний з `run_forever()`) — уникає дублювання.
`db.BACKUP_FORMAT_VERSION` (не `webapp.py`) — доступна з `monitor.py`
без циклічного імпорту (`webapp.py` вже імпортує `monitor`).
`perform_auto_backup()` пише JSON у `AUTO_BACKUP_DIR` (дефолт поруч
з `DB_PATH`, обчислюваний — тому поза UI-редактором, той самий клас,
що `DB_PATH`), ротація залишає `AUTO_BACKUP_KEEP_COUNT` (дефолт 4)
найновіших файлів.

**Telegram send-retry** (`telegram_notify.send_message()`) — до
`TELEGRAM_SEND_RETRIES` (дефолт 1) повторних спроб з `TELEGRAM_SEND_RETRY_DELAY_SEC` (дефолт 2с) затримкою, ЛИШЕ для `requests.RequestException` (мережеві помилки). `for...else` на рівні спроб:
`break` одразу після отриманої HTTP-відповіді (успіх чи ні - повтор
на HTTP-рівня помилку типу "chat not found" нічого не змінить),
`else`-гілка (виконується, лише коли цикл завершився БЕЗ `break`)
записує помилку, лише якщо ВСІ спроби дали мережевий збій.

**Фонова відправка** (`monitor._BackgroundSender`) — у робочому циклі
`_notify()` лише ставить повідомлення в чергу (до 50, порядок
зберігається), надсилає окремий потік. Без інтернету одне сповіщення
проходить усі таймаути й повтори (~62 с на чат), і раніше весь цей час
watchdog стояв, а `/healthz` перевищував поріг свіжості — healthcheck
перезапускав монітор посеред відправки. Відправник запускається лише в
`run_forever()` і зупиняється в `finally` (SIGTERM → `SystemExit`),
чекаючи чергу до 10 с; поза циклом `_notify()` синхронний (тести й
разові виклики детерміновані). Бекап у Telegram — теж через нього.

**Постійне з'єднання бота** — `getUpdates` (~3500 довгих запитів на
добу) іде через одну `requests.Session` лише в потоці `_run_loop`
(без TLS-рукостискання на кожен запит); відповіді на команди з пулу
потоків — без неї (Session не потокобезпечна). Після мережевої помилки
сесія перестворюється (WAN-failover міг лишити з'єднання на мертвому
маршруті).

## Сповіщення про встановлення очікуваної версії

Окремо від "🔄 прошивка змінилась" (будь-яка зміна) — `/settings`
дозволяє вказати ОЧІКУВАНУ версію, чи кілька через кому (той самий
формат, що `telegram_chat_ids`) — корисно, коли SpaceX випускає різні
номери версій для різних апаратних ревізій під однією умовною
версією. Матч на будь-яку з перелічених версій дає "✅ Останнє
оновлення встановлено". `db.parse_version_list()` — спільний helper,
`services.check_target_version_reached()` — module-level функція (не
метод класу).

**Дедублікація**: `dish_target_notified` зберігає трійку (`dish_id` +
версія + повний target-список) — природно скидається при зміні
списку. `dish_id` у ключі — якщо один Pi моніторить різні фізичні
Starlink з часом (заміна обладнання), дедублікація без `dish_id`
блокувала б сповіщення для нового пристрою при збігу з версією
попереднього.

`/api/target-versions` (GET/POST) — CRUD, GET повертає `dish_current`/
`router_current` для першочергового введення в UI. POST приймає новий
список лише якщо КОЖЕН кандидат не старіший за вже відому версію
(`db.is_older_version()`/`version_key()` — толерантний компаратор для
`YYYY.MM.DD.mrXXXXX.N`, дата-префікс домінує). Якщо хоч один
кандидат старіший — відхиляється весь список для поля.

**`db.version_channel()`** — витягує буквений префікс build-сегмента
(`mr`/`cr`). Різні апаратні ревізії можуть отримувати оновлення з
незалежних build-каналів одночасно з різними датами — пряме
порівняння дат між каналами хибно відхиляло валідні кандидати.
`_find_older_candidates()` порівнює candidate лише проти baseline
того самого каналу; без явного каналу — fallback на глобальне
порівняння.

**Rollback-узгодження**: якщо dish/router реально відкотився
(SpaceX-side) після введення target для новішої версії, candidate,
що точно збігається з фактично встановленою версією, завжди
дозволяється незалежно від старішого попереднього target — захист
від описок лишається непорушним.

Часткова відмова між полями (dish vs router) — валідне поле
зберігається, невалідне відхиляється окремо з поясненням. Порожній
рядок — команда очистити поле. Відповідь API завжди містить
`message` з реальним результатом.

`services.check_both_targets_reached()` — комбіноване "🎉" при
одночасному збігу обох компонентів, доповнює per-component
сповіщення. Викликається з обох циклів опитування (dish/router
незалежні). Не входить у backup/restore — internal dedup-стан, не
user-налаштування.

**Функції, спільні для watchdog, веб-кнопки і Telegram-бота** (модуль `app/services.py`): `version_in_target_list()`,
`check_target_version_reached()`, `check_both_targets_reached()`,
`upsert_dish_and_notify()`, `upsert_router_and_notify()`,
`check_updates_now()` — поза класом `Watchdog`, приймають `notify_fn`
замість `self._notify`.

**`IGNORED_ROUTER_ALERTS`** (`wired_mesh_not_using_wan_iface`, `lan_eth_slow_link_100`) —
відкидається в джерелі, `starlink_client.get_router_info()`, поруч з
`IGNORED_DISH_ALERTS`. Одна точка в джерелі покриває всі читання (монітор, ручна перевірка, Telegram `/status`, що читає роутер напряму), включно з майбутніми.

**`telegram_bot._api_call()`** явно перевіряє `ok`-поле відповіді Telegram (відхилений запит, напр. понад 4096 символів, інакше проходить непоміченим — "команда не відповідає"). `/id` без аргументу
обмежена `TELEGRAM_ID_LIST_MAX_ITEMS` (найвразливіша до ліміту
команда), з "…і ще N" поясненням при обрізанні.

Автоматичну міграцію колонок при `init_db()` (`ALTER TABLE ... ADD COLUMN`) мають
`metrics`, `router_status` і `events`; `system_metrics`, `known_devices` і `settings` —
ні. Нова колонка в будь-якій таблиці має додаватись і в `SCHEMA`, і в міграцію:
`CREATE TABLE IF NOT EXISTS` не чіпає наявну таблицю, тож база на Pi (`history.db`)
не отримає колонку без `ALTER`. Тест `test_schema_change_in_unmigrated_table_requires_migration` фіксує поточні колонки таблиць без міграції.

## Backup/restore налаштувань

`GET /api/settings-backup` віддає JSON (Telegram bot token, chat_ids,
enabled, auto_reboot_enabled,
dish/router_target_version, історія відомих Starlink-пристроїв
(`known_devices` — dish_id, версії ПЗ/апаратні, часові мітки),
`env_params` — лише перевизначені параметри app/config.py) —
завантажується браузером як файл. `POST /api/settings-restore`
приймає той самий формат і застосовує лише відомі поля (env_params
через `config_editor.save_values()`, застосовується після рестарту
сервісів). `known_devices` через `db.merge_known_devices()` — НЕ
перезаписує dish_id, що вже є в цільовій БД (INSERT OR IGNORE):
локальна БД реально працюючого watchdog'а вважається авторитетнішою
за статичний backup-знімок з невідомо якого моменту в минулому.
Bot token у файлі — у відкритому вигляді, файл backup потрібно
берегти як secret.

## Періодична відправка backup у Telegram (app/telegram_notify.py:send_document)

`send_document()` — та сама retry/eth0-fallback інфраструктура, що
`send_message()` (`_request_with_eth0_fallback()` з `**kwargs`,
підтримує `files=` без змін), але через Telegram Bot API's
`sendDocument`-endpoint (multipart/form-data, не JSON). Файл
відкривається **заново** для кожного chat_id окремо (`with open(...)
as f` усередині циклу) — file handle споживається один раз при
завантаженні, повторне використання того самого відкритого файлового
об'єкта для другого запиту дало б порожнє тіло другому отримувачу
(перевірено живим тестом: обидва chat_id реально отримують файл
повного розміру).

`Watchdog._maybe_send_backup_to_telegram()` (`monitor.py`) — окремий,
незалежний таймер від `AUTO_BACKUP_INTERVAL_SEC` (створення файлу) —
`TELEGRAM_BACKUP_INTERVAL_HOURS` (типово тиждень). Знаходить
**найновіший** (`max(..., key=os.path.getmtime)`) `.json`-файл у
`AUTO_BACKUP_DIR`, надсилає його. Таймер (`last_telegram_backup_sent_ts`) ініціалізується `time.time()` у `__init__()` (не `0.0`) —
інакше кожен рестарт сервісу негайно надсилав би файл, незалежно від
реально минулого інтервалу. Таймер оновлюється **безумовно, до самої
спроби відправки** — провал (напр. Telegram тимчасово недоступний) не
має спричиняти повторні спроби щоцикл опитування (~10с), а чекати
повного інтервалу.

Викликається в `run_forever()` окремою задачею `_Periodic` з `interval=None`
(щоітерації; не всередині задачі створення backup з `enabled=AUTO_BACKUP_ENABLED`) —
метод сам обробляє власні помилки й оновлює власний таймер
безумовно всередині себе, зовнішній `try/except` тут — лише
додатковий запобіжник від зовсім неочікуваних винятків.

**`services.send_latest_backup_to_telegram()`** — спільна логіка
"знайти найновіший backup + надіслати" винесена в окрему функцію
рівня модуля  - і
`Watchdog._maybe_send_backup_to_telegram()` (періодичний виклик, з
власною перевіркою `TELEGRAM_BACKUP_ENABLED`/інтервалу навколо), і
`webapp.py:/api/send-backup-telegram` (ручна кнопка "📨 Надіслати
backup у Telegram" на `/settings`) викликають цю саму функцію -
жодного дублювання логіки пошуку найновішого файлу чи запису події.
Ручний endpoint **навмисно ігнорує** `TELEGRAM_BACKUP_ENABLED` (той
параметр стосується лише автоматичного розкладу) - користувач явно
натиснув кнопку, очікує негайну дію незалежно від periодичних
налаштувань. Розрізняє два різні "немає що надсилати" сценарії з
окремими повідомленнями для UI: каталог `AUTO_BACKUP_DIR` ще не
існує (жодного backup ще не було зроблено) vs каталог існує, але
порожній (усі backup видалені ротацією чи вручну).

## Категоризація параметрів на /settings (app/config_editor.py)

`EDITABLE_PARAMS` (53 записи) — кожен має `category`
(`monitoring`/`reliability`/`telegram`/`gpio`), `CATEGORY_LABELS`
дає людський підпис для кожної. `/api/env-config` повертає обидва
разом (`{"params": [...], "category_labels": {...}}`).

3 реальні `STARLINK_`-env-змінні, які `config.py` читає, НАВМИСНО відсутні з `EDITABLE_PARAMS` (задокументовано коментарями поруч із кожним визначенням у `config.py`): `AUTO_BACKUP_DIR` (обчислюваний дефолт поруч із БД), `DB_PATH` (зміна шляху до БД
через веб-UI, поки сервіс уже читає/пише в стару, вимагала б ручної
міграції даних без явного попередження) і `WEBUI_HOST` (self-lockout
ризик — зміна адреси прослуховування через сам веб-інтерфейс могла б
відрізати користувача від `/settings` з іншого пристрою в мережі).
Обидва тести (`test_all_config_env_vars_are_in_settings_except_documented_exceptions`, `test_intentionally_excluded_settings_are_still_read_by_config`) перевіряють це у обидва боки — жоден новий
параметр не забутий у `/settings` без задокументованої причини, і
ці винятки лишаються реально читаними `config.py`, не випадково
видаленими взагалі.
`static/settings.js:loadEnvConfig()` групує параметри в `Map` за
`category` (зберігаючи порядок першої появи — той самий, що в
`EDITABLE_PARAMS`, не алфавітний), малює `<h3 class="env-category-head">` перед кожною групою.

**Мотивація** (запит користувача, після власного зауваження в
аудиті про 59+ параметрів у плоскому списку): плаский список без
структури важко сканувати оком, шукаючи конкретний параметр серед
50+. Групування — суто UI-зміна, не впливає на `save_values()`/
валідацію/env-файл (`category` — метадані для рендерингу, не
частина логіки збереження).

Два тести (`test_every_param_has_valid_category`, `test_no_orphan_category_labels`) перевіряють узгодженість у **обидва боки**: кожен
параметр має валідну категорію, і кожна категорія реально
використовується хоч одним параметром (не залишиться підпис для
вже спорожнілої групи).

**Межі значень.** `_validate_value()` перевіряє не лише тип, а й діапазон
(`config_editor.LIMITS`, для `DISPLAY_ROTATION` ще й `CHOICES`) і
скінченність `float` (`float()` приймає `nan`/`inf`/`1e999`; `isfinite()` —
лише для float, бо на дуже великому int вона кидає `OverflowError`). Нуль
лишено допустимим лише там, де він означає "вимкнено" (піни, автовимкнення
підсвітки, `AUTO_BACKUP_KEEP_COUNT`, затримки). Нульові таймери — небезпечні:
"0" означає "на кожній ітерації" (бекап у Telegram кожні 10 с),
`HISTORY_DAYS=0` видаляв би всю історію щогодини, `WEBUI_PORT=0` — випадковий
порт. Тести: кожен числовий параметр має межі, дефолти в межах, реальні
перевизначення користувача (21 рядок `env`) в межах, кордони приймаються, а
на крок за кордоном — ні. Ручна правка `env` не проходить цих меж, але й не валить сервіси: `config.py` читає змінні лише через `_env_int`/`_env_float`/`_env_bool`/`_env_text` — некоректне значення (порожнє `STARLINK_X=`, `abc`, `nan`, `1e999`) замінюється типовим із попередженням у журналі (раніше падав ІМПОРТ у 45 із 56 змінних, тож вмирали всі процеси, зокрема `/settings`, яким це можна виправити). Булеві приймають `1/true/yes/on` і `0/false/no/off` (раніше лише `"1"`: ручне `true` мовчки вимикало функцію); адреси й шляхи не бувають порожніми (порожній `DB_PATH` означав би тимчасову БД, тобто тиху втрату даних). Пауза опитування має ще й запобіжник `monitor._poll_pause()` (за межами 1..3600 → 10 с + попередження в лог).

Перевірки значення — таблиця `_VALIDATORS` за типом параметра
(`_check_bool`, `_check_number`, `_check_str`; кожна повертає текст
помилки або `None`, `ValueError` від `int("abc")` ловить
`_validate_value`).  `test_every_param_type_has_a_validator` вимагає запис для кожного типу з `EDITABLE_PARAMS` (невідомий тип інакше проходив би без перевірки мовчки).

Адреси (`STARLINK_DISH_ADDR`/`STARLINK_ROUTER_ADDR` — єдині
вільнотекстові параметри) приймаються лише як `host:порт` (ім'я, IPv4
або IPv6 у дужках; порт 1–65535 обов'язковий; `_address_problem()`).

## Керування Raspberry Pi (веб)

`pi_power.execute_pi_power_action()` (`app/pi_power.py`, спільний
модуль для веб-дашборду, фізичної кнопки й `display.py` — див.
"Повідомлення на дисплеї при reboot/poweroff" нижче) — для
`/api/system-reboot`/`/api/system-shutdown`: виконати команду через
`run_system_command()` (обмежений sudo, `/etc/sudoers.d/starlink-monitor` — навмисно вузько, конкретні команди, не blanket `ALL=(ALL)
NOPASSWD: ALL`), записати подію в журнал, надіслати Telegram-
сповіщення про результат.

## Фізична кнопка виключення (GPIO)

Окремий процес (`app/shutdown_button.py`, сервіс
`starlink-shutdown-button.service`), не інтегрований у `monitor.py`
чи `webapp.py` — свідома ізоляція, бо GPIO-доступ вимагає групу
`gpio` і `python3-libgpiod` (системний пакет, не pip), а не всі
установки мають фізичну кнопку.

## HTTP API веб-інтерфейсу

Усі маршрути Flask-застосунку (`app/webapp.py`). Автентифікації немає —
свідоме рішення власника (доступ лише з довіреної мережі), але POST із
чужого сайту відхиляється (403, `_reject_cross_site_posts`:
перевіряються `Origin` і `Sec-Fetch-Site`, які браузер виставляє сам);
curl і скрипти без цих заголовків працюють як раніше. Зміни й дії — ЛИШЕ
через POST (GET на них дає 405: захист від префетчу браузера й
краулерів); перед руйнівними діями веб-інтерфейс просить підтвердження
(`confirm()`); тіло запиту обмежене 5 МБ (інакше 413). Таблиці нижче
звіряє з реальними маршрутами тест
`test_http_api_reference_matches_routes`.

**Сторінки й службові**

| Метод | Шлях | Призначення |
|---|---|---|
| GET | `/` | дашборд |
| GET | `/settings` | параметри моніторингу, Telegram, backup |
| GET | `/stats` | журнал подій |
| GET | `/manifest.json` | PWA-маніфест (динамічний, мовою інтерфейсу) |
| GET | `/healthz` | свіжість даних для зовнішнього моніторингу й healthcheck-таймера: 200 або 503 |

**Читання стану**

| Метод | Шлях | Призначення |
|---|---|---|
| GET | `/api/status` | поточний стан тарілки (останній запис метрик) |
| GET | `/api/router-status` | стан роутера |
| GET | `/api/system-status` | метрики Pi: CPU, пам'ять, диск, температура |
| GET | `/api/events` | журнал подій (`?limit=N`, N у межах 1..500) |
| GET | `/api/config` | нечутливі налаштування для дашборда |
| GET | `/api/target-versions` | поточні й очікувані версії прошивок |
| GET | `/api/telegram-config` | налаштування Telegram; токен лише замаскований |
| GET | `/api/env-config` | поточні значення параметрів для `/settings` |
| GET | `/api/settings-backup` | усі налаштування одним JSON-файлом |

**Зміна налаштувань** (POST)

| Метод | Шлях | Призначення |
|---|---|---|
| POST | `/api/set-language` | мова інтерфейсу (одна для веб і Telegram) |
| POST | `/api/auto-reboot` | вмикає/вимикає авто-reboot при готовому оновленні |
| POST | `/api/target-versions` | очікувана версія (кілька через кому); старіші за відому відхиляються |
| POST | `/api/telegram-config` | токен, chat_id, увімкнення сповіщень |
| POST | `/api/env-config` | зберегти параметри: тип і межі перевіряються, усе або нічого |
| POST | `/api/settings-restore` | відновити налаштування з JSON (з підтвердженням) |

**Дії** (POST)

| Метод | Шлях | Призначення |
|---|---|---|
| POST | `/api/check-updates` | ручна перевірка стану оновлень (`services.check_updates_now()`) |
| POST | `/api/telegram-test` | перевірка токена й доступності бота |
| POST | `/api/send-backup-telegram` | надіслати останній створений backup у Telegram |
| POST | `/api/reboot-dish` | перезавантажити тарілку (з підтвердженням) |
| POST | `/api/env-config-restart` | перезапустити `starlink-monitor.service`, потім `starlink-webui.service` (з підтвердженням) |
| POST | `/api/system-reboot` | перезавантажити Raspberry Pi (з підтвердженням) |
| POST | `/api/system-shutdown` | вимкнути Raspberry Pi (з підтвердженням) |

## Стійкість і безпека: годинник, одночасність, нескінченні значення, обрив живлення, міжсайтові запити, привілеї root

**Годинник стрибнув назад** (ручна зміна часу, RTC, збій NTP; Pi без RTC
після аварійного вимкнення). Таймери в пам'яті й вибір "останнього"
запису працюють на настінному часі. `_Periodic` і пакетний запис метрик
вважають, що "пора", і при від'ємному минулому часі; мітки
`last_reboot_ts`/`last_telegram_backup_sent_ts` з майбутнього скидаються
на зараз (`_clamp_future_timestamps`: захист від reboot-loop
зберігається, вікно рахується від моменту зсуву);
`db.get_latest_metric()`/`get_latest_system_metric()` ігнорують рядки з
`ts` пізніше "зараз + 600 с" (`_FUTURE_TOLERANCE_SEC`). Журнал подій не
фільтрується (старі події не мають зникати). Вимір до виправлення при
зсуві на 2 год: 6 із 7 періодичних задач і запис метрик мовчали,
авто-reboot зависла тарілка не отримувала, дашборд показував online при
вже offline.

**Одночасні виклики** (монітор, веб-кнопка і потоки Telegram-бота —
різні потоки й процеси): "прочитати → вирішити → записати" над спільним
станом атомарне. `sqlite3` починає транзакцію лише перед записом, тож
читання не захищене: `_upsert_known_device` тепер із `BEGIN IMMEDIATE`,
прапорці "вже сповіщено" (`*_notified`, `both_targets_notified`) ставить
`db.claim_setting()` (повертає, чи саме цей виклик встановив значення).
Вимір до: 8 потоків → 8 однакових сповіщень про одну зміну прошивки.
Компроміс: прапорець ставиться ДО сповіщення — якщо `notify_fn` кине
виняток, повторної спроби не буде (наші `notify_fn` не кидають).

**Нескінченні значення.** `±inf` у метриці давав `Infinity` у відповіді
API — це невалідний JSON, `JSON.parse` у браузері падає, і дашборд
переставав оновлювати статус і системні метрики (підтверджено наскрізно
в `jsdom`). Два шари: `db._finite()` (при записі `NULL`) і
`_FiniteJSONProvider` у `webapp.py` (будь-яке `inf`/`NaN` у відповіді →
`null`, зокрема в рядках, збережених до виправлення). Кожен шар
перевіряється окремо.

**Фронтенд без вбудованого тексту.** Увесь видимий текст — через `t()`;
`test_frontend_has_no_hardcoded_cyrillic_text` забороняє кирилицю в JS і
шаблонах поза коментарями, `console.*` і `t()`, включно з атрибутами
(`placeholder`).

**Обрив живлення.** Файли, які перезаписує сам застосунок
(`/etc/starlink-monitor/env` зі `/settings` і `backup-<epoch>.json`),
пишуться через `atomic_io.atomic_write_text()`: тимчасовий файл у тому ж
каталозі → `fsync` → `os.replace` → `fsync` каталогу; права існуючого
файлу зберігаються (новий — 0600: у файлах може бути токен Telegram).
Раніше `open(path, "w")` спершу обнуляв файл, і обрив між обнуленням і
записом лишав порожній чи обірваний `env` (станція мовчки втрачала всі
перевизначення) або обірваний backup, який вважався б "найновішим". Для
`env` це можливо, бо `/etc/starlink-monitor` належить користувачу
сервісу й є в `ReadWritePaths` юніта веб-інтерфейсу. Виміряно: 60
`SIGKILL` у випадковий момент запису — нова версія 0 пошкоджених `env`,
старий `open("w")` 50 з 60 (порожній чи обірваний); `SIGKILL` між
`mkstemp` і `os.replace` лишає `.atomic-*.tmp`, їх прибирає наступний
запис (лише старші за 10 хв, за точним шаблоном).

**Ротація автобекапів** (`services.perform_auto_backup`): сортування
числове за epoch в імені (рядково `backup-9999` більше за
`backup-1790000000`), щойно записаний файл ніколи не видаляється. Раніше
після зсуву годинника назад новий backup мав найменше ім'я й видалявся
тим самим викликом, що його створив: автобекап мовчки нічого не
зберігав, поки годинник не "наздожене".

**Міжсайтові запити (CSRF).** Автентифікації немає, тож сторінка з
будь-якого сайту, відкрита в браузері будь-якого комп'ютера LAN, могла
надіслати "просту" форму (`text/plain`, без прелайту) на
`/api/system-shutdown` чи `/api/system-reboot` і вимкнути станцію разом
з інтернетом (виміряно: виконувались усі POST-ендпоінти).
`_reject_cross_site_posts` відхиляє POST, у якого `Sec-Fetch-Site` не
`same-origin`/`none` або `Origin` не збігається з `Host` (`null` теж
блокується). Не закрито: DNS-rebinding (запит із чужого імені, що
резолвиться в IP станції, для браузера "same-origin") — закрити можна
списком дозволених `Host`, але це обмежило б звернення за довільними
іменами, тож лишено на рішення власника.

**Привілеї: root виконує лише файли root.** Два юніти працюють від root
— `starlink-monitor-healthcheck` (раз/хв, `systemctl restart`) і
`starlink-wan-failover` (кожні 30 с, `nmcli`) — і запускають скрипти з
`/opt/starlink-monitor/scripts`; те саме робить адміністратор: `sudo
bash .../update.sh`. Раніше `install.sh` віддавав усе дерево користувачу
сервісів (`chown -R $RUN_USER`), тож компрометація будь-якого
непривілейованого процесу (веб-інтерфейс без автентифікації, монітор,
дисплей) давала шлях до root: переписати скрипт і почекати хвилину. Блок
`root-owned-scripts` в `install.sh` (після всіх кроків від `RUN_USER`:
`venv` і `pip` потребують запису) робить root-власником `$PROJECT_DIR` і
`scripts/`; самого права на файл замало — власник батьківського каталогу
підміняє `scripts/` цілком. `app/` і `venv` лишаються за користувачем
сервісів (fetch-юніт оновлює `app/vendor`; під час роботи сервіси й так
не пишуть у `/opt` через `ProtectSystem=strict`). `sudoers` дозволяє
користувачу сервісів рівно чотири команди (`systemctl restart` двох
сервісів, `reboot`, `poweroff`), без шаблонів. Тест
`test_install_security.py` виконує цей блок і від імені `nobody`
намагається переписати скрипт, додати файл і підмінити каталог — до
блоку атаки вдаються, після ні; нові root-юніти поза `scripts/` він
відхиляє.

## Залежності модулів (app/) і шари

Точка входу сервісу (модуль із `logging.basicConfig`: `monitor`, `webapp`,
`display`, `shutdown_button`) — НЕ бібліотека: жоден інший модуль її не
імпортує. Спільна логіка живе в бібліотечних модулях:

- `services.py` — відстеження версій прошивок і бекапи, що потрібні водночас
  Watchdog (`monitor`), веб-інтерфейсу і Telegram-боту.  Веб-процес завдяки цьому не вантажить `monitor` (11 модулів `app/`).
- `pi_power.py` — reboot/poweroff, зокрема `shutdown_from_button()` (спільна
  для `shutdown_button` і `display`).
- `db.py` — шар даних: НЕ залежить від `i18n`/`labels`/Telegram/веб-шару.
  `check_integrity()` повертає КОД причини (`not_a_database: <деталь>`), а
  людський текст будує споживач (`services.describe_integrity_problem()`) .

Гарантує `tests/test_architecture.py`: граф імпортів із AST (включно з
лінивими) без жодного циклу; точки входу не імпортуються іншими модулями;
`db` не залежить від шару подання. `Watchdog` лишається одним класом у
`monitor.py` (розбиття не рекомендовано — `docs/decisions-log.md`).

## Цикл монітора: періодичні задачі (`_Periodic`)

Усе періодичне в `Watchdog.run_forever()` — задачі `_Periodic(action, interval,
error, enabled)` у фіксованому порядку (`Watchdog._periodic_tasks()`): метрики Pi →
роутер → prune (1 год) → ANALYZE/VACUUM (доба) → перевірка цілісності БД →
автобекап (`enabled=AUTO_BACKUP_ENABLED`) → відправка бекапу в Telegram
(`interval=None`: щоітерації, власний таймер всередині). Правила: перше
спрацювання одразу після старту (`last=0`); інтервал читається з конфігу щоразу;
`last` оновлюється і ПІСЛЯ збою (повтор через інтервал, не щоітерації); виняток
логується, а не валить цикл.  Пакетний запис метрик
(`flush_metrics_buffer`) лишається окремо: його таймер спільний зі скиданням при
зміні стану.

## Повідомлення на дисплеї при reboot/poweroff (app/pi_power.py)

Спільний модуль для трьох джерел дії (веб-дашборд `webapp.py`,
фізична кнопка `shutdown_button.py`, і `display.py` — та сама кнопка,
спільна функція `pi_power.shutdown_from_button()`, не дублювання коду) — `execute_pi_power_action()` виконує
`systemctl reboot`/`poweroff`, записує подію, надсилає Telegram.

**Показ повідомлення на TFT-дисплеї - через DB-сигнал, не прямий
виклик `display.py`**: це окремий процес, що ексклюзивно тримає
SPI-запит, тому неможливо намалювати щось на екрані напряму з іншого
процесу (той самий клас обмеження, що вже вирішувався для LED-
активності через GPIO character-device API). `db.set_setting(pi_power.PENDING_ACTION_SETTING_KEY, action)` записується ПЕРЕД
реальним викликом `systemctl`. `display.py` опитує цей setting у
своєму швидкому (~100мс, `DISPLAY_BUTTON_POLL_INTERVAL_SEC`) циклі
кнопки — НЕ чекає звичайний 5-секундний `DISPLAY_REFRESH_SEC`-цикл
оновлення статусу, бо часу до SIGTERM від самого `systemctl reboot/poweroff` замало. Виявивши сигнал, малює `_draw_power_action_message()`
і одразу завершує `run_forever()` (`return`, не продовжує звичайний
цикл — процес все одно скоро буде вбитий).

**`DISPLAY_SHUTDOWN_MESSAGE_DELAY_SEC`** (типово 2с, застосовується
лише якщо `DISPLAY_ENABLED=1`) — затримка ПЕРЕД реальним `systemctl`-
викликом у `pi_power.py`, дає час 100мс-циклу дисплея реально
побачити сигнал і намалювати кадр ДО того, як сам процес дисплея
буде вбитий.

**Сигнал прибирається ПЕРЕД виконанням реальної команди, не ПІСЛЯ**
— другий реальний баг, знайдений користувачем на практиці (перший
фікс, описаний нижче, лишав race condition). Якщо цю функцію
викликає `webapp.py`, вона виконується всередині процесу
`starlink-webui.service`. Коли САМЕ ЦЕЙ процес ініціює `systemctl
reboot`, systemd починає ГЛОБАЛЬНУ зупинку всіх сервісів — включно
з тим самим `starlink-webui.service`. `SIGTERM` міг прийти РАНІШЕ,
ніж код після `run_system_command()` встигав виконати очищення —
сигнал лишався в БД, і після реального перезавантаження `display.py`
бачив цей застарілий сигнал і малював повідомлення ПІСЛЯ, а не
до/під час reboot (симптом, з яким користувач звернувся повторно).
На момент цього рядка сигнал уже виконав свою єдину мету
(`display.py` встиг побачити його й намалювати повідомлення під час
затримки вище) — подальше виконання команди відбувається без нього.

**Реальна помилка, знайдена живим тестом, не в production-коді, а в
API-дизайні**: перша версія `notify_fn: Callable[[str], Any] =
telegram_notify.send_message` як early-bound default-параметр
обчислюється ОДИН раз при імпорті модуля - `patch("app.telegram_notify.send_message")` у тестах не міг його замінити (default вже
"заморожений" як посилання на оригінальну функцію). Виправлено на
lazy-визначення (`notify_fn: Optional[...] = None`, `if notify_fn is
None: notify_fn = telegram_notify.send_message` всередині функції) -
краща практика незалежно від тестів, уникає прихованого "заморожування"
залежності при імпорті.

**Символи на дисплеї для повідомлення** — перша версія використовувала
`⏻`/`🔁` (Unicode symbol/emoji), автоматизована перевірка `font.getmask(ch).getbbox() is not None` хибно підтвердила "гліф є" - лише
РЕАЛЬНИЙ рендеринг зображення показав порожні "тофу"-квадрати
(fallback-гліф теж дає непорожній bbox). Замінено на `●` (той самий
символ, що вже підтверджено працює в `_status_lines()` для online/
offline індикатора).

## LED активності SD-картки (GPIO)

На відміну від кнопки/дисплея — **не окремий процес**, частина
`monitor.py` (watchdog-цикл), бо реагує на кожен реальний commit у
SQLite, а не на зовнішню подію на власному таймері. `app/activity_led.py:ActivityLed` — інкапсулює GPIO-стан; `init()` викликається раз
на старті `run_forever()`, реєструє `blink` як callback через
`db.set_activity_callback()`. `app/db.py:get_conn()` викликає цей
callback **лише** після успішного `conn.commit()` (не при винятку/
rollback — LED не має блимати на провалених записах).

**Лише watchdog-процес ініціалізує LED, не `webapp.py`** — уникає
конфлікту двох процесів за один ексклюзивний GPIO-запит (gpiod
character-device API не дозволяє двом процесам одночасно тримати
запит на ту саму лінію). `webapp.py` не імпортує `activity_led`
взагалі.

**Неблокуючий `blink()`** — вмикає LED синхронно, вимкнення
відкладається через `threading.Timer(blink_sec, ...)` (daemon-потік,
не заважає завершенню процесу) — сам запис у БД не отримує додаткової
затримки. Послідовні `blink()`-виклики (напр. dish-flush і system_
metrics в одному циклі) скасовують попередній таймер (`Timer.cancel()`)
перед стартом нового — LED лишається рівно увімкненим між ними, не
блимає нервово. Перевірено живим тестом: два `blink()` з малим
інтервалом дають послідовність `[1, 1, 0]` (не `[1, 0, 1, 0]`).

`gpio_utils.open_output_line()` — симетрична до `open_input_line()`
(gpiod v1/v2-сумісність), але `Direction.OUTPUT`/`LINE_REQ_DIR_OUT`
замість `INPUT`, і `set_value(int)` замість `get_value()`.

`ACTIVITY_LED_PIN=0` (дефолт, вимкнено) — той самий принцип opt-in,
що кнопка й дисплей. `starlink-monitor.service` отримав
`SupplementaryGroups=gpio` , `install.sh` уже додавав `RUN_USER`
до групи `gpio` для кнопки/дисплея, тому додаткових кроків
встановлення не потрібно.

- Увімкнено за замовчуванням на `GPIO27` (`SHUTDOWN_BUTTON_GPIO_PIN=27`);
  `0` вимикає — сервіс одразу виходить з кодом 0, не помилка
- `gpiod` (character-device API, не застарілий `RPi.GPIO`) слухає
  пін з внутрішнім pull-up; утримання довше
  `SHUTDOWN_BUTTON_HOLD_SEC` (типово 3с) → `sudo systemctl poweroff`
- venv створюється з `--system-site-packages`, щоб бачити системний
  `python3-libgpiod` (pip-версія gpiod не завжди чисто збирається
  без системних заголовків `libgpiod-dev`). Побічний ефект: `pip
  install` під час встановлення може вивести попередження про
  конфлікт залежностей сторонніх системних пакетів (напр.
  `types-flask-migrate` вимагає `Flask-SQLAlchemy`) — це не
  стосується коду проєкту (`Flask-SQLAlchemy`/`Flask-Migrate` ніде
  не імпортуються), встановлення завершується успішно
  (`Successfully installed ...`), попередження безпечно ігнорувати
- Статус (увімкнено/пін/час утримання) віддається через `/api/config`

## /healthz та PWA

`GET /healthz` — читає `db.get_latest_metric()["ts"]`, порівнює з
`config.POLL_INTERVAL_SEC * 3`; `503` якщо watchdog не оновлював
метрики довше цього порогу (сервіс завис/впав, хоч webui й далі
відповідає). Не пише подій у журнал — придатний для частого
зовнішнього опитування.

PWA: `/manifest.json` (динамічний Flask-endpoint, не статичний файл -
name/description перекладаються поточною мовою через `app/i18n.py`)
+ `static/sw.js` (service worker) + `static/pwa.js` (реєстрація SW,
підключена в усіх 3 HTML-шаблонах). Іконки `icon-192.png`/
`icon-512.png` згенеровані з `logo.png` (вписані в квадрат на
`--sky-900` фоні). Service worker кешує лише `/static/*`
(network-first, cache fallback) — принцип "не кешувати API-відповіді
на рівні SW" не змінився (застарілі дані без чіткого маркування були
б оманливими).

**Офлайн-fallback статусу** (`static/dashboard.js`, окремо від SW) —
інша задача: показати ОСТАННІЙ ВІДОМИЙ стан з ЯВНИМ маркуванням
застарілості, коли Pi недосяжний з телефону (не CDN/статика, а сам
локальний Pi — типовий мобільний сценарій: вийшов з WiFi-зони дії
Pi). `localStorage` (не `IndexedDB` — дані це один невеликий JSON-
об'єкт "останній latest", транзакції/великий обсяг не потрібні,
простий синхронний API достатній) зберігає `{latest, cachedAt}` при
кожному успішному `/api/status`. При невдалому fetch —
`_loadCachedStatus()` рендерить кешовані дані тим же кодом
(`_renderStatusData()`, винесений з `refreshStatus()` для
перевикористання), і банер `"⚠️ Немає зв'язку з Pi — показано
останній відомий стан (X хв тому)"` (`fmtAgo()` в `common.js` — той
самий формат, що `telegram_bot.py._fmt_ago()`). Це вирішує занепокоєння
з попереднього абзацу explicit маркуванням, не суперечить йому.

## Темна/світла тема

CSS custom properties в `static/style.css` — та сама семантика
змінних (`--sky-900`, `--text-hi` тощо) для обох тем, `[data-theme=
"light"]`-селектор інвертує значення. Знайдено й виправлено **7
хардкоджених hex-кольорів** поза `:root`-блоками під час впровадження
(градієнт `body`, warn/crit border, hover/active стани кнопок) — без
цього light-тема застосувалась би лише частково.

Застосування — inline `<script>` в `<head>` (єдиний, у `templates/base.html`: його наслідують усі сторінки через `{% extends %}`, блоки `title`, `content`, `page_script`), читає
`localStorage['theme']` **синхронно, до завантаження `style.css`**
(без цього — помітний "спалах" неправильної теми при кожному
завантаженні сторінки, FOUC). Критично важливий порядок у `<head>`:
скрипт має стояти **після** `<meta name="theme-color">` (інакше
`document.querySelector('meta[name="theme-color"]')` повертає `null`
— цей самий баг був знайдений і виправлений під час реалізації,
`try/catch` рятував від краху сторінки, але синхронне оновлення
статус-бару мобільного браузера просто не спрацьовувало б) і **до**
`<link rel="stylesheet">` (щоб усе ще запобігати FOUC для CSS).

`static/theme.js` (окремий файл, не в `common.js` — той не
підключений на `/settings`, а перемикач саме там) — `applyTheme()`,
викликається з `toggle`-обробника на `/settings` і оновлює й
`data-theme` атрибут, і `<meta theme-color>` (узгоджений колір
статус-бару мобільного браузера з фактичним фоном сторінки), і
`localStorage`.

## /stats — повна статистика

Головна сторінка показує лише 5 останніх подій журналу.
`/stats` (`templates/stats.html`, `static/stats.js`) — повний журнал
подій (`limit=300`), без інших елементів дашборду. "Очистити" на
обох сторінках — лише локально в браузері (`eventsClearedLocally`
в кожному JS-файлі окремо, БД не зачіпається), той самий підхід,
що вже був на головній.

**Дата-групування журналу** (`static/common.js:fmtDateHeader()`): 300
подій за `HISTORY_RETENTION_DAYS` (типово 14 днів) охоплюють багато
днів, а `fmtTime()` показує лише час. `refreshEvents()`
(`static/stats.js`) групує події (БД: `ORDER BY ts DESC`) за календарним
днем, вставляючи `.log-date-header` при зміні дня ("Сьогодні"/"Вчора",
далі повна дата); `dateKey` — за локальним часовим поясом браузера
(`Date.getFullYear/Month/Date()`, не `ts/86400`), щоб межа групи
збігалась із тим, що бачить користувач. Головна сторінка (5 подій)
групування не має — компактний віджет.

## Системний WAN-failover (scripts/wan_failover_check.sh)

Окремо від eth0-fallback у Python-коді (`telegram_notify.py`, працює
лише для конкретних HTTP-запитів проєкту) — системний рівень:
`starlink-wan-failover.timer` кожні ~30с запускає
`wan_failover_check.sh`, який `ping -I wlan0` перевіряє реальний
інтернет через wlan0 і через **nmcli** (`connection modify
ipv4.route-metric` + `device reapply`) підвищує/знижує пріоритет
дефолтного маршруту wlan0 (50 ⟷ 9999) залежно від результату. Пряма
зміна через `ip route` тут не годиться — NetworkManager сам володіє
wlan0 і періодично перевідновлює власний metric з конфігурації
з'єднання, ігноруючи зовнішні зміни таблиці маршрутів в обхід себе.
Коли wlan0 демотовано, eth0 (metric 1002) автоматично стає дефолтним
для **всієї системи** (apt, curl тощо), не лише для нашого коду.

**Важливо**: `192.168.1.0/24` (router) має автоматичний kernel-scope
маршрут (це власна підмережа wlan0-інтерфейсу) — завжди пріоритетніший
за дефолтний, незалежно від metric. Але `192.168.100.0/24` (dish) **не
має** такого автоматичного маршруту — весь трафік туди йшов лише через
дефолтний маршрут, і при демотуванні wlan0 dish ставав недосяжним
(реальний виявлений баг). Виправлено: `install.sh` при першому
встановленні додає постійний `nmcli +ipv4.routes "192.168.100.0/24
$WLAN_GW"` на wlan0-з'єднанні — окремий явний маршрут, незалежний від
стану WAN-failover.

**Гістерезис**: перемикання metric стається лише після
`REQUIRED_CONSECUTIVE=3` поспіль однакових результатів ping-перевірки
(стан — `/run/starlink-wan-failover/state`, tmpfs, у межах
`RuntimeDirectory=` — потрібне для запису під `ProtectSystem=strict`).
Без цього кожен
`nmcli device reapply` на мить розриває маршрут до dish, і сам факт
переключення впливав на результат наступної ж перевірки — петля
самопідживлення (реальний виявлений баг: часті короткі флапи dish,
підтверджено точним часовим збігом у `journalctl`).

root-сервіс — `CapabilityBoundingSet` звужує навіть root до
`CAP_NET_ADMIN`+`CAP_NET_RAW` (ping потребує raw-сокети).
`uninstall.sh` відновлює нормальний metric wlan0 через той самий
nmcli-підхід, якщо він був демотований на момент видалення.

## Watchdog для watchdog-а (scripts/watchdog_healthcheck.sh)

`Restart=always` на `starlink-monitor.service` рятує від crash, але
не від зависання (deadlock/livelock) — процес технічно живий,
systemd цього не бачить. `starlink-monitor-healthcheck.timer`
(раз/хв) опитує вже наявний `GET /healthz` (окремий процес
`starlink-webui.service`, незалежний від можливого зависання
watchdog-потоку) — якщо відповідь не `200`, примусовий `systemctl
restart starlink-monitor.service`. `OnBootSec=90` — довше за перший
цикл опитування, щоб уникнути хибного restart одразу після
завантаження ("no data yet" у `/healthz` саме по собі не є
деградацією, `ok=True`).

## Періодична оптимізація БД (db.vacuum_and_analyze)

`ANALYZE` раз на добу в `monitor.py` (окремий таймер, рідше за
`prune_old()` — щогодини) і на старті сервісу; `VACUUM` — **лише коли
вільних сторінок ≥ 30%** (`db._VACUUM_MIN_FREE_RATIO`, функція повертає,
чи він виконувався). `VACUUM` переписує ВСЮ БД (вимір: база 6.5 МБ →
13.7 МБ записів на SD), тому не щодоби й не на кожен запуск сервісу. Після
щоденного `prune_old()` звільняється ~1/`HISTORY_DAYS` сторінок (20% при
5 добах), але нові записи одразу заповнюють їх — файл після `VACUUM` за
добу виростав би до колишнього розміру. Справді потрібен він після
зменшення `HISTORY_DAYS` чи великого видалення. Окреме autocommit-з'єднання
(не `get_conn()` з WAL) — простіше й надійніше для команди, що вимагає
ексклюзивного доступу.

## Журнал запитів веб-інтерфейсу

Werkzeug пише рядок у журнал на КОЖЕН запит, а дашборд опитує сервер
~3500 разів на годину на відкриту вкладку — це ~83 000 рядків (~8 МБ) на
добу, які йдуть на SD-картку й через Python-логування. `_QuietSuccessfulGets`
(фільтр логера `werkzeug`) відкидає лише успішні GET (2xx/3xx); лишає POST-дії
(перезавантаження, зміна налаштувань — з IP джерела: єдиний слід дій, бо
автентифікації немає) і всі помилки 4xx/5xx. Тести — на справжньому
HTTP-сервері: `test_client()` цей шлях обходить.

## Ротація журналу systemd

`install.sh` ідемпотентно дописує `SystemMaxUse=200M` у
`/etc/systemd/journald.conf` (лише якщо там ще немає власного
значення користувача) — без обмеження journald міг би з часом
накопичити помітний обсяг логів на SD-картці.

## fstrim.timer

`install.sh` вмикає стандартний systemd-таймер `fstrim.timer` (частина
`util-linux`, майже напевно вже встановлена на Raspberry Pi OS — лише
`enable --now`, без встановлення пакету) — та сама лінія, що
`PRAGMA synchronous=NORMAL` у `db.py`: зменшення зношення SD-картки,
періодичний TRIM консолідує вільний простір на flash-носіях, що його
підтримують. Безпечно навіть якщо конкретна SD-картка TRIM не
підтримує — `fstrim` тоді просто нічого не робить, не шкодить.
Перевірка наявності юніта (`systemctl list-unit-files fstrim.timer`)
перед enable — на випадок застарілого `util-linux` без цього таймера.
Навмисно НЕ вимикається в `uninstall.sh` — загальносистемна корисна
практика, не специфічна для цього проєкту.

## Фізичний TFT-дисплей (app/display.py)

Окремий процес (той самий патерн, що `shutdown_button.py`) —
`run_forever()` виходить миттєво, якщо `DISPLAY_ENABLED=0`. Кожні
`DISPLAY_REFRESH_SEC` читає дані з БД і передає їх у `_redraw()`, який
малює кадр через Pillow і надсилає через `ST7789.image(image)`
(об'єкт бібліотеки Adafruit CircuitPython, не модуль `display.py`) — лише якщо кадр змінився:
uptime показується з точністю до хвилини, тож ~11 з 12 перемальовувань
були марними, а вночі екран годинами не змінюється.

**Структура циклу.** `run_forever()` лише ініціалізує залізо (`_open_button()` —
лінія кнопки; частково відкритий стан при збої зберігається, бо `release()` потрібен
у `finally`) і крутить цикл; усю логіку однієї ітерації виконує
`DisplayController.tick()` в тому ж порядку, що був у тілі циклу: повідомлення про
reboot/poweroff (ДО всього) → кнопка → таймери підсвітки (автовимкнення, flash) →
перемальовування. Метод повертає `True`, коли дисплей має завершитись. Допоміжні
функції (`_set_backlight`, `_redraw`, ...) контролер викликає як глобальні імена
модуля, тож їх можна підміняти в тестах; логіку перевіряють юніт-тести
`tick()` без заліза й без циклу.
`_status_lines()` повертає структурований список `{"kind": ...,
"text": ...}` (+ `"progress"` для `kind="update"`) — не плаский
список за позицією (рядок оновлення опційний, індекси були б
крихкими).

`_redraw()` малює за `kind`: `"status"` (статус+uptime в одному
рядку, lime/red), `"update"` (окремий рядок для тарілки й роутера,
з прогрес-баром `draw.rectangle()`), `"firmware"` (повні мітки,
влазять завдяки landscape canvas при ROTATION=90/270).
`DOWNLOADING_UPDATE_IMAGE_FAILED`/`GETTING_TARGET_VERSION_FAILED`
для роутера приховуються (`HIDDEN_ROUTER_STATES` — той самий підхід,
що `static/dashboard.js`) — тимчасова хмарна помилка SpaceX, не
справжня проблема. `_truncate_to_width()` обрізає `…` для будь-якого
рядка, що не влазить (виміряно через `draw.textlength()`).

Ініціалізація через `board`/`digitalio`/`busio` (Blinka) — CS
bit-banged GPIO (не апаратний CE0/CE1), бібліотека сама коректно
виводить RST з reset ДО SPI-команд, rotation 0/90/180/270 для
будь-якого aspect ratio через програмний `img.rotate()`, підсвітка
керується напряму окремим `digitalio`-об'єктом (бібліотека не має
вбудованого `set_backlight()`).

**Важливо для rotation=90/270**: `image()` перевіряє розмір
зображення ПІСЛЯ `rotate()` проти `ST7789.width`/`height` (самі не
змінюються параметром rotation) — `_redraw()` тому створює полотно з
транспонованими розмірами саме для 90/270, інакше `ValueError` для
прямокутного дисплея. `OFFSET_LEFT`/`OFFSET_TOP` діють на рівні
фізичної GRAM-адресації, застосовуються вже після повороту — не
потребують перерахунку залежно від rotation.

Паспортна роздільна здатність (SKU MSP1901) — 170×320, portrait,
підтверджена офіційною документацією виробника. `BLK` вмикається
HIGH; якщо підключено напряму до 3.3V — `DISPLAY_BL_PIN=0`. Потребує
`dtparam=spi=on` (install.sh попереджає, якщо не увімкнено).
`OFFSET_LEFT` дефолт 35 — емпірично підтверджене значення для цієї
моделі (див. `decisions-log.md` про діагностику кольорового шуму,
спершу помилково прийнятого за апаратний дефект). `SPI_SPEED_HZ`
дефолт 40МГц — консервативний для джампер-дротів, можна підняти при
якісному монтажі.

**Кнопка** — та сама, що `SHUTDOWN_BUTTON_GPIO_PIN` (не окремий пін):
коротке перемикає підсвітку, довге вимикає Pi через
`pi_power.shutdown_from_button()` (спільна з `shutdown_button.py`).
Обробляється в цьому самому циклі (не окремим сервісом — керування
BL-піном можливе лише з процесу, що тримає `digitalio`-об'єкт).
`shutdown_button.py` сам себе вимикає, коли `DISPLAY_ENABLED=1`, щоб
не конкурувати за той самий GPIO. `gpio_utils.ButtonPressTracker` —
спільна, чиста стейтфул-структура детекції короткого/довгого
натискання, використовується і тут, і в `shutdown_button.py`. Кнопка
опитується кожні `BUTTON_POLL_INTERVAL_SEC` (0.1с), редрав — лише раз
на `DISPLAY_REFRESH_SEC` (окремий таймер, не блокуючий сон).

**Автовимкнення підсвітки** (`BACKLIGHT_AUTO_OFF_SEC`, дефолт 60с):
`_should_auto_off()` — чиста функція. `last_activity_ts` оновлюється
при кожному ввімкненні — рахує час від моменту ввімкнення, не від
загальної бездіяльності.

**Flash при зміні статусу оновлення** (`UPDATE_FLASH_SEC`, дефолт 5с):
`_update_state_changed()` — чиста функція, порівнює update_state
відносно попереднього опитування (перше зчитування НЕ вважається
зміною). При зміні — `last_activity_ts=now` (критично: інакше
60с-auto-off міг би вимкнути підсвітку до завершення коротшого
5с-flash), окремий `flash_until_ts` з явним guard проти конфлікту
двох таймерів. Ручне натискання під час flash скасовує
`flash_until_ts`.

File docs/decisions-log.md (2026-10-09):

# Журнал рішень

Хронологічний запис значущих технічних рішень і знайдених багів.

## Мережа, WAN-failover і Telegram через eth0

- Статичні IP в `install.sh` — інтерактивно й лише при першому
  встановленні (`MODE=="install"`): неправильні мережеві дефолти можуть
  обірвати SSH. `dhcpcd` вимикається лише в межах цього кроку
  (конфліктує з NetworkManager). Підтвердження читається через `tr -d
  '[:space:]'` (у терміналі буває прихований `\r`).
- Пошук профілю NetworkManager (`find_nm_connection()`): спершу активні
  з'єднання (`nmcli connection show` без `--active` дає порожній DEVICE
  для неактивних), потім властивість `connection.interface-name`, потім
  `connection.type` — лише якщо такий профіль рівно один (профілі
  netplan часто без `interface-name`; діагноз дав `bash -x`-трейс від
  користувача).
- wlan0 має нижчий route-metric за eth0, тож зовнішній інтернет іде
  через wlan0 першим: коли Starlink без інтернету, мовчать і Telegram, і
  `fetch_starlink_grpc.sh` (він тепер починає з `curl --interface
  eth0`).
- Telegram через eth0 (`_request_with_eth0_fallback()` у
  `send_message`/`test_connection`/`_api_call`): прив'язка сокета до
  IP-адреси джерела НЕ форсує інтерфейс (Linux обирає його за таблицею
  маршрутизації за адресою призначення) → `SO_BINDTODEVICE` (потрібен
  `CAP_NET_RAW`: `AmbientCapabilities`, сумісно з `NoNewPrivileges`).
  Якщо системний DNS теж мовчить — ручна резолюція через eth0-сокет і
  запит напряму на IP з `Host`-заголовком і `verify=False` (відкрите
  питання — у «Аудитах»).
- WAN-failover (`starlink-wan-failover`): зміна `ip route` в обхід
  NetworkManager ненадійна (він володіє wlan0 і відновлює metric) →
  `nmcli connection modify ipv4.route-metric` + `nmcli device reapply`;
  маршрут до dish (192.168.100.0/24) не має автоматичного kernel-route
  (на відміну від 192.168.1.0/24) → постійний `nmcli +ipv4.routes`;
  `reapply` на мить розриває маршрут до dish і сам спричиняв флапи
  (петля самопідживлення) → гістерезис: перемикання лише після 3
  однакових результатів підряд; `/run` недоступний за
  `ProtectSystem=strict` → `RuntimeDirectory=` +
  `RuntimeDirectoryPreserve=yes`.
- `install.sh` пропонує вимкнути (не видаляти) `bluetooth`,
  `avahi-daemon`, `triggerhappy`, `ModemManager` — кожну перевіряє
  окремо; мережеві `ssh`, `NetworkManager`, `dhcpcd` не пропонуються
  (headless-пристрій без фізичного доступу).

## Процеси, systemd, привілеї і vendor-файл

- Starlink Mini — два логічні пристрої (dish + router) з різними
  `DeviceInfo`, enum-станами й alert-полями; схему підтверджено `grpcurl
  describe`, не здогадкою (`starlink_client.py`, `labels.py` побудовані
  на ній).
- `NoNewPrivileges` вимкнено на `starlink-webui` і `starlink-display`
  (кнопку виключення читає display; `shutdown_button.py` — окремий
  процес): вони викликають `sudo systemctl reboot/poweroff`, а прапорець
  блокує sudo незалежно від sudoers. Урок: після перенесення логіки
  кнопки в `display.py` unit-файл забули оновити, і довге натискання не
  вимикало Pi. `starlink-monitor.service` (sudo не викликає) лишається з
  прапорцем.
- `StartLimitIntervalSec/Burst` — у `[Unit]`, не в `[Service]` (у
  неправильній секції systemd мовчки ігнорує). `ProtectSystem=strict`
  успадковується дочірніми процесами незалежно від sudo: кожен
  записуваний шлях — явно в `ReadWritePaths=`.
- Фізична кнопка — окремий процес: GPIO вимагає групу `gpio` і
  `python3-libgpiod` (зайва залежність без кнопки), вимкнена за
  замовчуванням (pin=0, чистий вихід), `Restart=on-failure` (не
  `always`: чистий вихід не циклить рестарт); venv з
  `--system-site-packages` для системного gpiod. gpiod 2.x (Bookworm+)
  має інший API → `_init_line_v1`/`_init_line_v2` за
  `hasattr(gpiod.Chip, "get_line")`. LED активності — частина
  `monitor.py` і потребує `SupplementaryGroups=gpio` (знайдено
  порівнянням з іншим GPIO-сервісом ще до тестування на залізі).
- Vendored `starlink_grpc.py` (`app/vendor/`): динамічне завантаження з
  GitHub при кожному встановленні означало залежність від інтернету й
  непередбачувані версії; `fetch_starlink_grpc.sh` лишився для опційного
  ручного оновлення.
- Логіка, потрібна і `Watchdog`, і веб-інтерфейсу, — у module-level
  функціях з параметром `notify_fn`: `webapp` і `monitor` — окремі
  процеси, а ручна "Перевірити оновлення" не сповіщала, бо логіка жила в
  методах `Watchdog`. Ту саму функцію `check_updates_now()` викликають
  кнопка дашборда й команда `/checkupdates`.
- Telegram-бот обробляє updates у пулі
  (`ThreadPoolExecutor(max_workers=3)`: блокуючі gRPC-виклики до ~15 с
  зупиняли polling), групуючи їх за `chat_id` (інакше `/reboot` і
  підтвердження йдуть у різних потоках і порядок ламається).
  `_api_call()` перевіряє поле `ok` відповіді (відхилений запит, напр.
  понад 4096 символів, інакше мовчки ігнорується; `/id` без аргументу
  обмежено `TELEGRAM_ID_LIST_MAX_ITEMS`) і не передає HTTP-таймаут під
  іменем `timeout` (колізія з long-poll Telegram → `http_timeout`).
- `last_reboot_ts` оновлюється при КОЖНІЙ спробі reboot, не лише при
  успіху (інакше повтор щоцикл замість `MIN_REBOOT_INTERVAL_SEC`); та
  сама помилка була й на update-ready шляху → спільний
  `_reboot_for_update_ready`.
- Pending-сигнал дисплея про reboot/poweroff очищується ПЕРЕД командою
  (після затримки для показу): `execute_pi_power_action()` виконується
  всередині `starlink-webui.service`, який `systemctl reboot` сам і
  зупиняє — SIGTERM міг прийти раніше за очищення, і `display.py` після
  перезавантаження малював застаріле повідомлення. Очищення лише при
  провалі лишало сервіс мертвим назавжди (`Restart=on-failure` не
  перезапускає чистий вихід).

## Дисплей і GPIO

- Бібліотека `adafruit-circuitpython-rgb-display` (ST7789): попередня
  мала RST-баг (підсвітка є, зображення немає: RST як output LOW і
  одразу `_init()`) і забороняла rotation 90/270 для прямокутних
  дисплеїв; обертання тепер програмне (`img.rotate()`), CS — bit-banged
  GPIO.
- Дефолти — паспортні 170×320 (landscape = поміняти WIDTH/HEIGHT).
  Помилковий висновок з емпіричного тесту: дефолти 320×170 "покращували"
  картинку лише як побічний ефект іншої зміни; кольоровий шум на SKU
  MSP1901 спершу вважали апаратним дефектом, а це зміщення GRAM
  (`DISPLAY_OFFSET_LEFT`/`_TOP` = 35/0, підтверджено емпірично).
- Без `fonts-dejavu-core` тихий fallback на `ImageFont.load_default()` —
  без кирилиці → пакет у `install.sh` і явне попередження в лозі.
  Символи `⏻`/`🔁` у DejaVu — "тофу"-квадрати (виявлено лише візуальним
  переглядом) → `●`.
- Спалах підсвітки при зміні стану оновлення оновлює `last_activity_ts`
  (інакше `_should_auto_off()` вимикав підсвітку раніше за спалах).
  Повідомлення про reboot/poweroff: `pi_power.py` пише DB-сигнал,
  `display.py` опитує його в швидкому 100-мс циклі кнопки.

## Сповіщення й прошивки (доменні правила)

- Придушені в Telegram (але пишуться в журнал):
  `MUTED_DISH_ALERTS={"roaming"}`,
  `MUTED_ROUTER_ALERTS={"install_pending"}`,
  `MUTED_ROUTER_UPDATE_STATES={"GETTING_TARGET_VERSION_FAILED"}`. Цикл
  оновлення dish: перехід у `DOWNLOADING_UPDATE_STATES` → "🔽 Розпочато",
  повернення в `IDLE` → "✅ Завершено"; `REBOOT_REQUIRED`/`FAULTED` мають
  власні повідомлення навіть при прямому переході.
- Журнал спроб watchdog при тривалій недоступності обмежено
  `MAX_LOGGED_CONSECUTIVE_FAILURES` (спроба N+1 дає фінальний маркер,
  далі мовчить; `reboot_dish()` викликається без змін). Групування
  reboot-спаму (`_notify_reboot()`): ковзне вікно timestamps,
  поріг+вікно → мовчазне групування до затишшя, тоді підсумок і скид
  (повідомлення про ПОЧАТОК групування прибрано).
- `upsert_known_device_*()` повертає `(real_change, old_version)` і
  перевіряє КОНКРЕТНЕ поле: dish і router створюють спільний рядок у
  різних циклах, тож перше заповнення "свого" поля не є зміною з None.
  Повідомлення "оновлена" чи "відкочена (можливо, SpaceX-side)" — за
  `db.is_older_version()`; відкат мовчазний (параметр сповіщення
  видалено, `known_devices` оновлюється).
- Очікувані версії (`/settings`): дедуплікація через збережене значення
  target (скидається новим target) і ізольована per-`dish_id` (різні
  фізичні тарілки з тим самим збігом версія+target блокувались хибно);
  `_version_key()` — толерантний компаратор `YYYY.MM.DD.mrXXXXX.N`
  (дата-префікс домінує); кілька кандидатів через кому (різні апаратні
  ревізії), відхиляється весь список, якщо хоч один старіший;
  channel-aware (`version_channel()`: mr/cr порівнюються лише в межах
  каналу); кандидат, що збігається з фактично встановленою версією,
  дозволений завжди (узгодження після rollback з боку SpaceX); dish і
  router валідуються незалежно; "🎉" — лише коли ОБИДВІ версії збіглися
  одночасно; порожній рядок очищає поле.
- Backup містить `known_devices`: `merge_known_devices()` — `INSERT OR
  IGNORE` (локальна БД авторитетніша за знімок); `format_version` 1→2,
  `env_params` — лише реально перевизначені значення, restore через
  `config_editor.save_values()` після рестарту сервісів. Резервні копії
  в Telegram: окремий інтервал; `send_document()` з тим самим
  retry/eth0-fallback; файл відкривається заново для кожного `chat_id`;
  кнопка ігнорує `TELEGRAM_BACKUP_ENABLED`;
  `send_latest_backup_to_telegram()` — спільна для розкладу й кнопки.
- Вимикаються параметрами: `STARLINK_NOTIFY_DISH_RECOVERY`,
  `STARLINK_NOTIFY_PI_STARTUP` (`pi_just_booted()` порівнює
  `psutil.boot_time()` з поточним часом, поріг 120 с, — відрізняє reboot
  від `systemctl restart`). Поведінкові timeout/interval-константи — у
  `config.py` (структурні дані — мітки, шляхи, SQL DDL — лишаються в
  модулях).

## Дані, SD-картка, надійність

- `PRAGMA synchronous=NORMAL` для WAL. Розглянуто і НЕ застосовано:
  `Storage=volatile` для journald — втрата історії `journalctl` між
  перезавантаженнями, а це критичний діагностичний інструмент.
- Буферизація dish-метрик: batch-INSERT раз на 30 с, `system_metrics`
  окремо раз на 60 с, flush при graceful shutdown (SIGTERM); оцінка
  ~19750 → ~4200 записів/добу (−79%); поріг свіжості `/healthz` враховує
  batch-інтервал (до цього збігався з ним точно).
- Надійність: `PRAGMA quick_check` щодоби (пошкодження → сповіщення й
  аварійний backup), автобекап із ротацією (увімкнено за замовчуванням),
  один повтор Telegram лише для мережевих помилок (не HTTP-рівня).
- Видалено `downsample_old_metrics()`/`metrics_downsampled` (живили
  видалені графіки): БД зберігає повну деталізацію (~5× більша) замість
  3 дні + 27 агрегованих. Зберігання — 14 діб (`STARLINK_HISTORY_DAYS`),
  `/stats` бере limit 300 (серверний cap 500 не чіпали — незалежний
  захист endpoint'у).
- Три write-only колонки (`metrics.currently_obstructed`,
  `router_status.bootcount`, `events.last_ts`) — запис припинено (NULL
  для нових рядків), схему не змінювали (рішення користувача);
  `known_devices` без очищення — навмисно (історія пристроїв для `/id`).
- Виміряно й не варте кешування: SQL-агрегація 2.74 мс, GPIO-polling
  0.21 мс/виклик. Фронтенд опитує `/api/status` раз на 1.5 с
  (`REFRESH_MS`, компроміс користувача між 1000 і 3000; dish опитується
  раз на 10 с, router на 35 с), прихована вкладка — раз на 30 с
  (`HIDDEN_REFRESH_MS`).

## Фронтенд, PWA і документація

- Мобільна адаптація: гнучкі ширини <480px, `safe-area-inset`, цілі
  дотику 44px, брейкпоінт <360px. Cache-busting: `_static_v()` додає
  `?v=<mtime>` до статичних URL (з `SEND_FILE_MAX_AGE_DEFAULT=3600`
  браузер показував стару поведінку після `update.sh`).
- PWA-офлайн: `localStorage` (не IndexedDB — простий JSON) з явним
  індикатором "X хв тому"; API service worker не кешує. Тема — CSS
  custom properties, `[data-theme="light"]`, inline-скрипт у `<head>`
  без FOUC (перед `<meta theme-color>`, інакше `querySelector` повертає
  null); жодних хардкоджених hex поза `:root`. Журнал на `/stats`
  групується за календарним днем (`fmtDateHeader()`), головна сторінка
  (5 подій) — ні.
- Інструкція оновлення — повний шлях
  `/opt/starlink-monitor/scripts/update.sh` (відносний падав поза
  розпакованим архівом). Якорі GitHub для emoji-заголовків мають
  лідируючий дефіс, а для складніших emoji — невидимий variation
  selector (підтверджено на справжньому рендері, тепер тримає тест
  змісту).

## Залежності й версії

- Піни `==` без `--upgrade`: `--upgrade` оновлював увесь файл, зачіпаючи
  hardware-критичний `adafruit-blinka`; `install.sh` оновлює пакети лише
  коли змінився requirements; major-розриви (protobuf, adafruit-blinka)
  не чіпаються без перевірки живим regression. `python3-dev
  build-essential` потрібні для компіляції `rpi_ws281x`/`RPi.GPIO`.
- Типізація: `mypy --strict` спершу давав 366 помилок (SQLite
  `dict(row)` і vendor-код), тому був пропорційний підхід; нині суворий
  режим для `app.*` — див. «Правила коду».

## Видалено або відхилено (не повертати без нової причини)

- "Оновлення системи" (apt-перевірка): поза призначенням проєкту
  (прошивки Starlink, не Pi OS) — видалено endpoint, метрику, кнопку,
  sudoers-правило й `ReadWritePaths=/var/lib/apt/lists`.
- Плановий reboot Starlink Mini по таймеру (повністю: функції,
  параметри, тести, документація); параметр сповіщення про відкат
  прошивки; сповіщення про зняття `obstruction_map_reset` (alert тепер
  ігнорується в джерелі).
- UI-графіки історії (видалені раніше; можливе повернення),
  `downsample_old_metrics()`, `Storage=volatile` для journald.

## Короткі уроки з аудитів коду

- Falsy-патерн `x = x or default` робить явний `0` (напр.
  `prune_old(days=0)` = "видалити все") нерозрізненим від "не передано"
  → перевіряти `is None`.
- Кожен параметр `config` має зустрічатись як `config.PARAM` (так
  знайдено `DB_INTEGRITY_CHECK_INTERVAL_SEC`, який ніколи не читався, бо
  `run_forever()` мав хардкоджене 86400); звіряти за реальним
  `os.environ.get()`, а не за назвою атрибута.
- Записи очікуваних підтверджень (`_pending_reboot_confirm`) чистити при
  кожному новому запиті (інакше витік пам'яті); об'єкт, який зупиняє
  `stop()`, створювати ДО реєстрації signal handler'а (вузьке вікно
  `NameError` при SIGTERM).
- Усі однакові за структурою гілки dish/router — у спільну функцію
  (`_validate_and_save_target()`, `run_system_command()`,
  `_validate_telegram_config()` + `_send_to_all_chats()`,
  `_reboot_for_update_ready`); рефакторинг лише там, де логіка справді
  однакова, а не лише схожа.
- Тест на кожен рефакторинг: наявні тести мають пройти БЕЗ змін; "легко
  тестується" в docstring без жодного тесту (`ButtonPressTracker`) —
  сигнал прогалини; нескінченні цикли в тестах зупиняти через
  `SystemExit` (не власний Exception-підклас: його ловить внутрішній
  `except Exception`). Аппаратні бібліотеки підміняти в `sys.modules`.
- Прямий живий тест знаходить те, що не бачить читання коду (порожнє
  значення мовчки ігнорувалось; контракт API без `message`); коментар,
  що посилається на контекст, якого вже немає, переписувати
  самодостатнім.

## Мультимовний інтерфейс (uk/en)

`app/i18n.py` (`TRANSLATIONS`, `t()`, `translator()`), мова в
`settings.ui_language` (дефолт uk, одна на все). Перекладено: 3 сторінки,
53 параметри з категоріями, Telegram-команди й усі 31 автоматичне
сповіщення (uk — побайтово як було), `/manifest.json` (динамічний),
README.en.md (окремий файл, синхронізувати вручну). НЕ перекладається:
журнал подій (українською), TFT-дисплей, `logger.*`. Уроки: `labels.py`
— функції, не module-level dict (кешувалось би назавжди в процесі, що
живе тижнями); `get_language()` ніколи не кидає виняток (зламана БД
обрушила б вимкнення Pi кнопкою, сторінки й бота). `test_i18n.py`
стежить за паритетом плейсхолдерів uk/en і наявністю кожного ключа.
Повідомлення інтерфейсу (результати кнопок /settings, відповіді API — 17
текстів) теж через i18n; журнал подій лишається українським. Зліпок 36
записів до/після: uk побайтово ідентичний; в англійському режимі
кирилиця лишилась лише в перевірці цілісності на зламаній БД (мову
прочитати неможливо → дефолт uk, задумано).

## Правила тестів: ізоляція БД, мережі, середовища

- Тест коду, що доходить до `i18n.t()`, — лише з `db_path` (інакше
  залишковий `ui_language='en'` з іншого тесту; так знайдено кілька
  flaky, зокрема один, помилково визнаний "безпечним" статичним оглядом).
- Фікстура `watchdog` фіксує `router_reachable=True`; жоден тест не
  ходить у мережу (Telegram-ретраї: `_get_eth0_ip -> None`).
- Відсутній пакет — `monkeypatch.setitem(sys.modules, m, None)`, не
  `.pop()`; `config.DISPLAY_ENABLED` відкочує autouse-фікстура.
- Перевіряти динамічно, не на око: плагін pytest із забороною TCP і UDP
  (DNS іде через `sendto`, не `connect`) → 0 з'єднань; порожня БД перед
  кожним тестом → увесь набір проходить.
- Ізоляція робочих шляхів — autouse-фікстура в conftest для КОЖНОГО
  тесту: env, тека бекапів і БД за замовчуванням → tmp (БД навмисно не
  ініціалізована: тест без `db_path` падає, а не читає чужий стан —
  структурно прибирає клас "мова з попереднього тесту"). Причина: 11
  тестів писали в справжній `/etc/starlink-monitor/env` (фікстура
  `client` ізолювала БД, але не `ENV_FILE_PATH`), README стверджував
  "без побічних ефектів". Аудит звернень до робочих шляхів 45 → 0;
  тест-запобіжник `test_tests_never_use_real_pi_paths`.
- Запуск тестів на самому Pi — лише в окремому venv, без
  `--break-system-packages` і без бібліотек `adafruit-*` (README), щоб
  жоден тест не торкнувся справжніх GPIO/SPI.

## Продуктивність, розмір сторінок і записи на SD

Цифри — вимір на x86 (на Pi абсолютні числа більші), якщо не сказано
інше.
- **i18n**: `translator()` + context processor — 1 SQLite-з'єднання на
  рендер замість 55 (13.7 → 2.1 мс); без TTL-кешу між запитами (мову
  змінює webapp, читає й monitor).
- **Розмір сторінок**: `window.I18N` — лише 121 ключ, що використовує JS
  (динамічні `t(var)` заборонені тестом), + `ensure_ascii=False`: `/`
  67.9 → 18.3 КБ.
- **`/api/status`** (кожні 1.5 с): прибрано `uptime_24h_pct` (~70% часу
  запиту, хибна через нічне вимкнення) — 2.21 → 0.60 мс. **Дашборд**:
  `/api/status` щотіку, журнал кожен 4-й тік, роутер і Pi кожен 10-й,
  `tick(true)` оновлює все: 9600 → 3480 запитів/год на вкладку.
- **TFT-дисплей**: дані читає цикл і передає в `_redraw()`; незмінний
  кадр не рендериться й не йде по SPI (uptime з точністю до хвилини): 17
  280 → 842 перемальовування на добу.
- **Пам'ять**: `pi_power` імпортує `telegram_notify` лише в момент
  сповіщення (дисплей і кнопка не тримають `requests`: 22 → 5 МБ).
  **Ледаче завантаження vendored gRPC**
  (`starlink_client._grpc_module()`, маркер `_UNLOADED`; веб-процесу він
  потрібен лише двом кнопкам): веб у простої 54.1 → 41.3 МБ, імпорт 244
  → 196 мс; після першого "Перевірити оновлення" RSS як раніше (57 МБ),
  монітор не змінився; блокування — щоб потоки не імпортували й не
  логували помилку кожен окремо.
- **Журнал systemd**: таймери WAN-failover (30 с) і healthcheck (60 с) —
  `LogLevelMax=notice` + `SyslogLevel=notice` (−13 000 рядків/добу на
  SD, вивід скриптів лишається; фільтр PID 1 потребує systemd ≥ 248 —
  ефект перевіряти на Pi).
- **Метрики dish** — пакетом раз на 30 с, але ЗМІНА `(online,
  update_state)` скидає буфер одразу
  (`test_unchanged_state_stays_batched`). **Telegram-бот**: `getUpdates`
  (~3500/добу) через одну `requests.Session` лише в потоці `_run_loop`
  (Session не потокобезпечна), перестворюється після мережевої помилки:
  20 запитів → 1 TCP-з'єднання. `cpu_percent(interval=None)`
  прогрівається при імпорті `system_metrics` (перший замір був
  беззмістовним 0.0).
- **Журнал запитів Werkzeug**: рядок на КОЖЕН запит (~83 000 рядків ≈ 8
  МБ/добу на вкладку); `_QuietSuccessfulGets` відкидає лише успішні GET,
  POST-дії (з IP) і помилки лишаються — єдиний слід дій без
  автентифікації (`test_client()` лог запитів обходить). **VACUUM лише
  за потреби** (вільних сторінок ≥ 30%) — див. `architecture.md`.
- Виміряно й НЕ змінювалось (щоб не повертатись): запити до БД по
  індексах, ендпоінти < 1 мс на 14 добах даних (`limit=500` — 3 мс);
  сторінки 12–18 КБ (gzip на LAN не потрібен); статика `max-age=3600` +
  ETag/304; `dnspython` імпортується лениво (+12.5 МБ лише в запасному
  шляху Telegram); CPU у простої — монітор 0.05%, веб 0.00% ядра; ≈12.7
  відкриття SQLite-з'єднання на опитування (~0.1% CPU навіть на Pi; кеш
  налаштувань відхилено); записи БД ~68 МБ/добу (≈25 ГБ/рік, менше
  0.1%/рік ресурсу SD) — AUTOINCREMENT/індекс по `ts` дали б −26%, але
  не варті ризику міграції; `.pyc` (компіляція ~35 мс на x86, ~0.3 с на
  Pi).
- Пастка виміру часу імпорту: з `PYTHONDONTWRITEBYTECODE=1` і видаленим
  `__pycache__` кожен запуск перекомпілює vendored файл (3.4 с замість
  90 мс) — міряти з прогрітим `.pyc`; пам'ять (RSS) від цього не
  залежить.

## Мережа й install.sh

WAN-failover — кожні 30 с. На Pi користувача мережевий блок install.sh
не застосувався; причину НЕ встановлено (висновок "баг install.sh"
відкликано), тож install.sh тепер перевіряє, що очікувана адреса є серед
фактичних (`grep -qxF`, не `!=`: кілька IPv4 давали хибне "УВАГА").
На WiFi-профілі `ipv6.method disabled`: IPv6 через мертвий Starlink-канал
блокував DNS/HTTPS. Мережевий блок виконується лише при першому
встановленні — для наявних систем ручна команда в README.

## Starlink вимкнено ≠ зависання тарілки

Dish і роутер (TCP до gRPC-порту, timeout 2 с — без WiFi Starlink
пакети йдуть через eth0 і чекають його повністю) недоступні 3
опитування поспіль (~30 с, гістерезис) → стан "Starlink вимкнено": без reboot і лічильника
збоїв, одна подія на вхід/вихід, Telegram лише при поверненні після >
`NOTIFICATIONS_MUTE_AFTER_SEC` (вибір користувача: "лише вранці"). Без
розкладів — стан визначається фактом. Ніч користувача (симуляція):
reboot 114→0, рядків журналу 5932→2. "Пропускаю авто-reboot" — один
запис на вікно очікування.

## Станція оновлення прошивок: контекст і рішення користувача

3–12 різних Starlink на день, на ніч вимикається. Відкрита WiFi
`STARLINK` без прив'язки до BSSID — ПРАВИЛЬНО (Pi підхоплює будь-який);
НЕ радити унікальну назву/пароль, розділення 2.4/5 ГГц чи прив'язку
BSSID. Дашборд на 0.0.0.0 без автентифікації — свідоме рішення
власника ("доступ маю тільки я"), не виносити як проблему.
Приховано повністю: `obstruction_map_reset` — фільтр у джерелі,
`starlink_client.IGNORED_DISH_ALERTS` (/status і check_updates_now()
читають в обхід poll_once); `DOWNLOADING_UPDATE_IMAGE_FAILED` —
`monitor.HIDDEN_ROUTER_UPDATE_STATES` (попередній стан не змінюється,
у /status — "немає оновлень").
Поле цільових версій прошивки не перевіряє формат — РІШЕННЯ КОРИСТУВАЧА,
не виносити як проблему ("abc" відхиляється як "старіша за версію того
самого build-каналу", "v1.2.3" приймається; шкоди немає — невалідна ціль
просто ніколи не спрацює). Стан роутера `GETTING_TARGET_VERSION_FAILED`
показується як "немає оновлень" скрізь (дашборд, дисплей, Telegram
/status), у журнал подій пишеться, у Telegram не надсилається.

## Розриви WiFi кожні 65.536 с — відома особливість, тему закрито

Роутери Starlink оголошують Country IE з порожнім кодом → ядро не може
застосувати → тайм-аут ~3.14 с → скидання регіону → через ~60 с
перевірка каналів → розрив `reason=3 locally_generated=1`. Виключено:
енергозбереження, сигнал, AP-deauth, друга мережа, база регіонів.
`iw reg set 00` не працює (скидання повертає регіон із cmdline); зміна
cmdline.txt не рекомендована (ризик headless-завантаження). Вплив на
моніторинг — нуль завдяки гістерезису.
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

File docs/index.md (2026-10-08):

# Індекс проєкту

Навігатор по файлах Starlink Monitor. Детальний технічний опис —
[`architecture.md`](architecture.md); історія рішень і виправлених
багів — [`decisions-log.md`](decisions-log.md); загальний
опис/встановлення — [`../README.md`](../README.md).

## Корінь

| Файл | Опис |
|---|---|
| `README.md` | Опис проєкту, встановлення, конфігурація, усі env-параметри |
| `README.en.md` | Той самий README англійською - синхронізувати вручну при зміні README.md |
| `requirements.txt` | Python-залежності (pip), встановлюються на Pi |
| `constraints.txt` | Закріплені ТРАНЗИТИВНІ версії (urllib3, idna, Werkzeug...): `pip install -r requirements.txt -c constraints.txt`; апаратні adafruit-* свідомо відсутні |
| `requirements-dev.txt` | Залежності розробки (mypy, pytest, ruff, pip-audit, html5lib) - НЕ встановлюються на Pi |
| `mypy.ini` | Конфігурація статичної типізації: суворий режим для `app/*`, м'який для `tests/`, `app/vendor/` виключено |
| `pytest.ini` | Мінімальна конфігурація pytest (`testpaths = tests`) |
| `ruff.toml` | Правила `ruff check` (F, B, E9, PLE, S; виключає `app/vendor/`); без `ruff format` |
| `.gitignore` | `__pycache__/`, `.mypy_cache/`, `.pytest_cache/`, `*.db` — не мають потрапляти в архів |
| `LICENSE` | Ліцензія |

## `app/` — Python-модулі

| Файл | Опис |
|---|---|
| `starlink_client.py` | gRPC-клієнт: статус dish/router, `reboot_dish()`; vendored gRPC-стек вантажиться ліниво (`_grpc_module()`) |
| `monitor.py` | Watchdog: цикл опитування, авто-reboot, логування подій, запуск Telegram-бота (точка входу) |
| `services.py` | Спільна логіка для monitor/webapp/telegram_bot: відстеження версій прошивок (`check_updates_now`, `upsert_*`, `check_*_targets_reached`), бекапи (`build_backup_dict`, `perform_auto_backup`, `send_latest_backup_to_telegram`, `check_db_integrity_and_notify`) |
| `webapp.py` | Flask, REST API, роздає `/`, `/settings`, `/stats`, `/healthz`; відхиляє POST із чужого сайту (CSRF), у JSON немає `Infinity`/`NaN` |
| `db.py` | SQLite: metrics, events, system_metrics, router_status, known_devices, settings; атомарні `claim_setting`/`BEGIN IMMEDIATE`, "останній" запис ігнорує рядки з майбутнього |
| `i18n.py` | Мультимовний інтерфейс (uk/en) - словник перекладів, `t()`, мова з settings |
| `telegram_notify.py` | Вихідні сповіщення |
| `telegram_bot.py` | Вхідні команди `/status`, `/checkupdates`, `/reboot`, `/id`, `/help` (`/start` = `/help`) |
| `atomic_io.py` | Атомарний запис файлів (тимчасовий файл → fsync → os.replace), права існуючого файлу зберігаються; для env і автобекапів |
| `labels.py` | Таблиці "код -> ключ перекладу" для станів оновлення й alert-прапорців (monitor.py + telegram_bot.py), `short_error()` для чату |
| `log_redact.py` | Очищення токена бота з текстів помилок і логів (`redact()`, `RedactingFilter`, `install()`) |
| `system_metrics.py` | Метрики Pi (CPU/RAM/диск/температура) |
| `shutdown_button.py` | Фізична кнопка виключення через GPIO (окремий процес) |
| `pi_power.py` | Спільний reboot/poweroff, `shutdown_from_button()`, DB-сигнал для дисплея |
| `activity_led.py` | Опційний LED активності SD-картки, частина monitor.py (не окремий процес) |
| `display.py` | Фізичний TFT-дисплей статусу (ST7789, SPI, окремий процес); `DisplayController.tick()` — логіка однієї ітерації без заліза |
| `gpio_utils.py` | Спільна gpiod v1/v2-логіка читання GPIO (shutdown_button.py + display.py) і запису GPIO (activity_led.py) |
| `config.py` | Конфігурація, env-змінні |
| `config_editor.py` | Читання/валідація (`_VALIDATORS`, `LIMITS`, формат адрес)/атомарний запис `/etc/starlink-monitor/env` через `/settings` |
| `vendor/starlink_grpc.py` | Vendored (не наш код) — gRPC-хелпери з sparky8512/starlink-grpc-tools (Unlicense) |
| `vendor/PROVENANCE` | Походження vendored файлу: upstream-коміт, дата, sha256 (тест звіряє з файлом); пише `fetch_starlink_grpc.sh` |

## `static/` — фронтенд

| Файл | Опис |
|---|---|
| `common.js` | Спільні для dashboard.js/stats.js: `fmtTime`, `fmtAgo`, `fmtDateHeader` |
| `theme.js` | Темна/світла тема - toggle на /settings, підключено на всіх 3 сторінках |
| `dashboard.js` | Логіка головної сторінки (`/`) |
| `settings.js` | Логіка сторінки налаштувань (`/settings`) |
| `stats.js` | Логіка сторінки статистики (`/stats`) |
| `pwa.js`, `sw.js`, `manifest.json` | PWA (встановлення як застосунок, offline-кеш) |
| `style.css` | Стилі усіх сторінок |
| `favicon.ico`, `icon-192.png`, `icon-512.png`, `logo.png` | Іконки |

## `templates/` — HTML

| Файл | Опис |
|---|---|
| `base.html` | Спільна основа всіх сторінок: `<head>` (мета, шрифти, тема без FOUC, `window.I18N`), закриття `.wrap` і скрипти; блоки `title`, `content`, `page_script` |
| `index.html` | Головний дашборд |
| `settings.html` | Сторінка налаштувань |
| `stats.html` | Сторінка статистики (журнал подій) |

## `systemd/` — unit-файли

| Файл | Опис |
|---|---|
| `starlink-monitor.service` | Watchdog + Telegram-бот |
| `starlink-webui.service` | Flask dashboard |
| `starlink-shutdown-button.service` | Слухає GPIO-кнопку виключення |
| `starlink-display.service` | Фізичний TFT-дисплей |
| `starlink-grpc-fetch.service` | Опційне ручне оновлення vendored `starlink_grpc.py` (не автоматичне) |
| `starlink-wan-failover.service`/`.timer` | Періодична перевірка інтернету через wlan0 |
| `starlink-monitor-healthcheck.service`/`.timer` | Раз/хв опитує `/healthz`, force-restart при зависанні |

## `scripts/` — bash

| Файл | Опис |
|---|---|
| `install.sh` | Повне встановлення (системні пакети, venv, sudo-права, systemd); після кроків від користувача сервісів каталог проєкту й `scripts/` стають власністю root |
| `update.sh` | Оновлення вже встановленого проєкту |
| `uninstall.sh` | Повне видалення |
| `fetch_starlink_grpc.sh` | Опційне оновлення vendored `starlink_grpc.py`: тимчасовий файл → перевірки (розмір, синтаксис, ChannelContext/get_status) → `.prev` → атомарна заміна; `--commit=<sha>`; пише `PROVENANCE` |
| `audit_deps.sh` | Аудит вразливостей закріплених залежностей (`pip-audit` по requirements.txt + constraints.txt) |
| `wan_failover_check.sh` | Перевірка інтернету через wlan0, коригування route-metric |
| `watchdog_healthcheck.sh` | Перевірка `/healthz`, force-restart при не-200 |
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

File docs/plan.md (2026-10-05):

# План проекту

## Зроблено

- [x] Моніторинг dish: latency, obstruction, uptime, стан
      оновлення ПЗ, попередження, dish_id
- [x] Моніторинг router: окрема прошивка, стан оновлення, попередження
- [x] Автоматичний reboot (watchdog + update-ready для dish і router)
      з runtime-перемикачем і захистом від reboot-loop
- [x] Веб-дашборд: живі метрики, журнал подій
- [x] Системні метрики Pi (CPU/RAM/диск/температура)
- [x] Telegram: вихідні сповіщення + вхідні команди `/status`,
      `/checkupdates`, `/reboot`, `/id`, `/help`
- [x] Одноразове сповіщення про підключення нової тарілки (dish_id)
- [x] Ручна перевірка стану оновлень з дашборду
- [x] Ручний reboot/shutdown самого Raspberry Pi з веб-інтерфейсу
- [x] Фізична кнопка виключення через GPIO (окремий сервіс, вимкнено за замовчуванням)
- [x] LED активності SD-картки через GPIO (частина monitor.py, вимкнено за замовчуванням)
- [x] Повідомлення на TFT-дисплеї при reboot/poweroff Pi (з кнопки або веб-дашборду)
- [x] install.sh: install/update режими, детекція суттєвих змін
- [x] update.sh: ручне оновлення через sha256-перевірку архіву
- [x] Дедублікація однотипних подій у журналі (повтори того самого
      kind+message стискаються в один запис з лічильником)
- [x] Backup/restore налаштувань (Telegram config, auto-reboot)
      одним JSON-файлом через веб-інтерфейс, автоматичний періодичний
      backup із ротацією
- [x] Список під'єднаних WiFi-клієнтів роутера на дашборді
- [x] Запам'ятовування версій ПЗ dish/router по dish_id (`known_devices`) +
      команда `/id [ID]` в Telegram-боті (список пристроїв або деталі)
- [x] Окрема сторінка `/settings` (Telegram, backup/restore)
- [x] Редагування параметрів `app/config.py` через веб-інтерфейс (`/settings`)
- [x] Фільтрація вибраних router alerts (не пишуться в БД/журнал/Telegram)
- [x] Опційне інтерактивне налаштування статичних IP (eth0/wlan0) в install.sh
      (лише при першій інсталяції)
- [x] Опційне вимкнення непотрібних для headless-моніторингу системних
      служб (Bluetooth/avahi/triggerhappy/ModemManager) в install.sh
- [x] Скрипт повного видалення проєкту (scripts/uninstall.sh)
- [x] Приглушення Telegram-звітів при безперервній недоступності dish
      довше 15 хв (журнал не зачіпається, відновлення завжди повідомляється)
- [x] `/healthz` для зовнішнього моніторингу (БД + свіжість метрик watchdog)
- [x] Встановлюваний дашборд (PWA: manifest, service worker, іконки)
- [x] Telegram eth0-fallback (SO_BINDTODEVICE + ручний DNS) при недоступному Starlink
- [x] Системний WAN-failover (wlan0↔eth0 route-metric) - для всієї системи, не лише Telegram
- [x] Watchdog для watchdog-а (healthcheck-таймер, force-restart при зависанні)
- [x] Періодичний ANALYZE SQLite (раз на добу); VACUUM — лише коли вільних сторінок ≥ 30%
- [x] Ротація журналу systemd (SystemMaxUse=200M)
- [x] Менша частота опитування дашборду при прихованій вкладці (visibilitychange)
- [x] Фізичний TFT-дисплей статусу (ST7789, SPI), вимкнено за замовчуванням
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

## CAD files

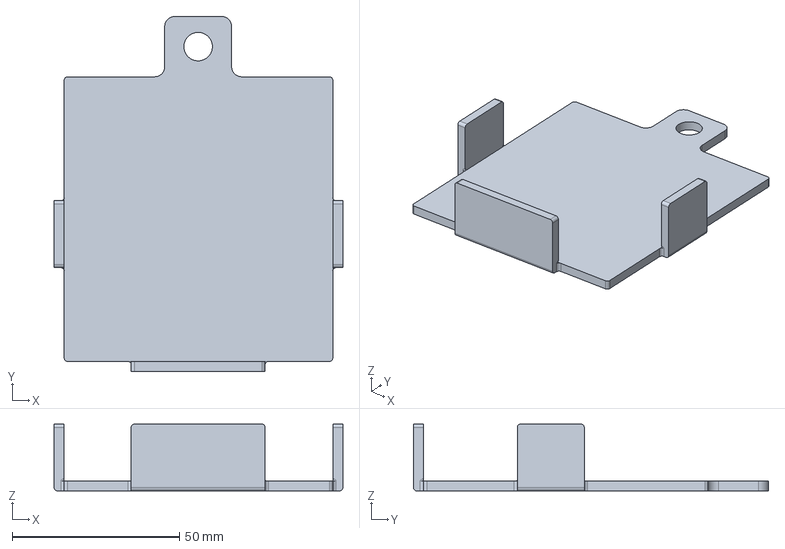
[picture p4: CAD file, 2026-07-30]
3D/starlink_monitor_case_wall_mount.FCStd
86.2 x 106.0 x 20.0 mm

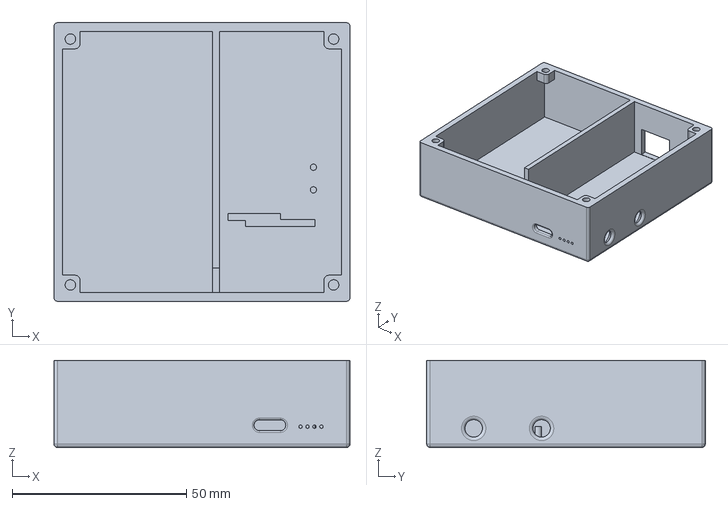
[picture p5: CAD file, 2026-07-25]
3D/starlink_monitor_case.FCStd
85.0 x 80.0 x 25.0 mm

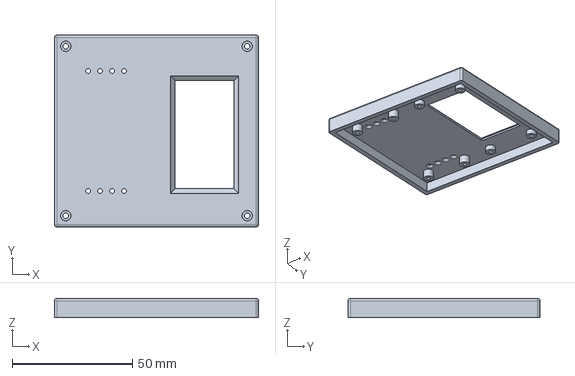
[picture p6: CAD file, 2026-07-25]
3D/starlink_monitor_cover_DISPLAY.FCStd
85.0 x 80.0 x 8.00 mm

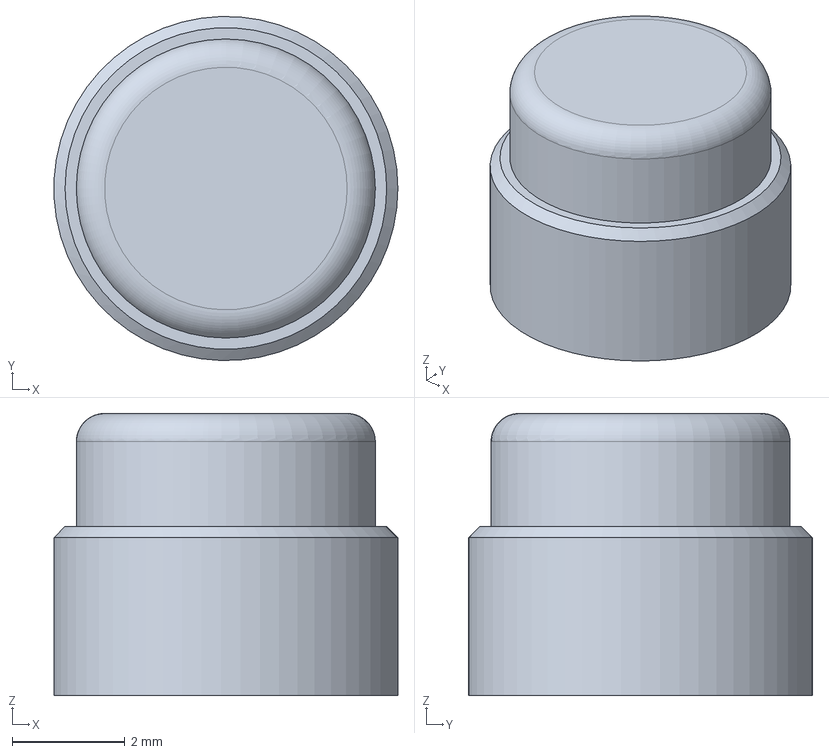
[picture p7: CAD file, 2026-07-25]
3D/starlink_monitor_knob.FCStd
6.10 x 6.10 x 5.00 mm

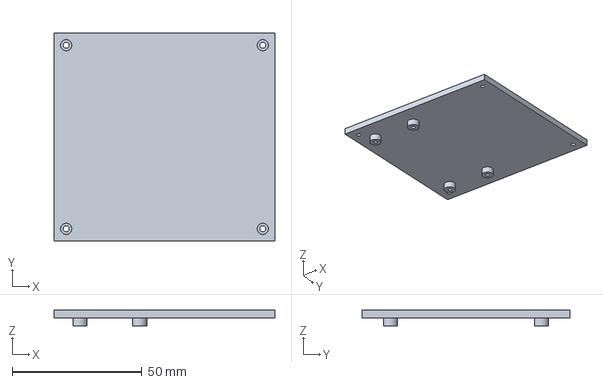
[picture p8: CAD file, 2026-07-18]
3D/starlink_monitor_cover.FCStd
85.0 x 80.0 x 6.00 mm

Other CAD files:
3D/starlink_monitor_case.stl
3D/starlink_monitor_case_wall_mount.stl
3D/starlink_monitor_cover.stl
3D/starlink_monitor_knob.stl

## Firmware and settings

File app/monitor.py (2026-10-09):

"""
Фоновий watchdog: опитує dish (POLL_INTERVAL_SEC) і router
(ROUTER_POLL_INTERVAL_SEC),
пише в БД, авто-reboot Mini при 3 умовах (watchdog failures,
update-ready dish, update-ready router) - див. docs/architecture.md.
Логує зміни стану/попереджень в events, дублює ключові події в
Telegram (не блокує цикл при помилках відправки).
"""
import logging
import queue
import signal
import threading
import time
from typing import Any, Callable, Optional, Union

import psutil

from app import activity_led, config, db, i18n, labels, log_redact, services, telegram_notify
from app.starlink_client import DishStatus, RouterInfo, StarlinkClient
from app.system_metrics import get_system_metrics
from app.telegram_bot import TelegramBot

logging.basicConfig(
    level=logging.INFO,
    format="%(asctime)s [%(levelname)s] %(name)s: %(message)s",
)
log_redact.install()   # токен бота ніколи не потрапляє в журнал (див. app/log_redact.py)
logger = logging.getLogger("monitor")


def pi_just_booted(threshold_sec: float = 120.0) -> bool:
    """Чи Pi РЕАЛЬНО щойно завантажився (не просто service-restart,
    напр. `sudo systemctl restart starlink-monitor.service` під час
    оновлення коду через update.sh) - порівнює system uptime
    (`psutil.boot_time()`, уже використовується в system_metrics.py)
    з порогом. Чиста функція (легко тестується без реального psutil-
    виклику через мокування)."""
    return bool(time.time() - psutil.boot_time() < threshold_sec)


# Ігноровані попередження dish і роутера відкидаються в джерелі -
# starlink_client.IGNORED_DISH_ALERTS / IGNORED_ROUTER_ALERTS.

# Стани оновлення ПЗ роутера, які не пишуться в журнал подій, не
# надсилаються в Telegram і показуються як "немає оновлень" (дашборд і
# TFT-дисплей ховають їх так само). DOWNLOADING_UPDATE_IMAGE_FAILED -
# тимчасова хмарна помилка завантаження на боці SpaceX, роутер сам
# повторює спробу; на станції оновлення прошивок - шум (рішення
# користувача). Попередній стан при цьому НЕ змінюється, тож
# повернення до завантаження після такої помилки теж не логується.
HIDDEN_ROUTER_UPDATE_STATES = frozenset({"DOWNLOADING_UPDATE_IMAGE_FAILED"})


def format_duration(seconds: float, tr: Callable[..., str]) -> str:
    """"8 год 20 хв" / "45 хв" - мовою перекладача tr (i18n.translator())."""
    minutes = max(0, round(seconds / 60))
    hours, minutes = divmod(minutes, 60)
    if hours:
        return f"{hours} {tr('dur_hours')} {minutes} {tr('dur_minutes')}"
    return f"{minutes} {tr('dur_minutes')}"


_POLL_PAUSE_DEFAULT_SEC = 10.0
# Стеля буфера dish-метрик у пам'яті, коли БД недоступна: ~доба опитувань по
# 10 с. Понад це відкидаються найстаріші (пам'ять на Pi Zero - 415 МБ).
_METRICS_BUFFER_MAX = 8640


def _poll_pause() -> float:
    """Пауза між опитуваннями. Значення з /settings уже перевірено (1..3600),
    але env-файл можна змінити й вручну: time.sleep() від'ємного/nan/inf
    кидає виняток ПОЗА обробником циклу і валив увесь процес монітора
    (crash-loop під systemd), а нуль гнав би цикл без пауз."""
    interval = config.POLL_INTERVAL_SEC
    return interval if 1 <= interval <= 3600 else _POLL_PAUSE_DEFAULT_SEC


# Скільки при зупинці сервісу чекати відправки вже поставлених сповіщень, с
_NOTIFY_DRAIN_TIMEOUT_SEC = 10


class _BackgroundSender:
    """Фонова відправка в Telegram: один потік, обмежена черга, порядок
    повідомлень зберігається. Раніше сповіщення йшли синхронно в циклі
    монітора: без інтернету одне проходило всі таймаути й повтори (~62 с
    на чат, ~2 хв на 2 чати) - watchdog стояв, /healthz перевищував поріг
    свіжості (60 с) і healthcheck примусово перезапускав монітор посеред
    відправки. Circuit breaker цього не розв'язав би: перше блокування
    однаково відбулось би до розмикання."""

    def __init__(self, maxsize: int = 50) -> None:
        self._queue: "queue.Queue[Optional[Callable[[], None]]]" = queue.Queue(maxsize=maxsize)
        self._thread = threading.Thread(target=self._run, daemon=True, name="tg-notify")
        self._thread.start()

    def submit(self, job: Callable[[], None], label: str) -> None:
        try:
            self._queue.put_nowait(job)
        except queue.Full:
            logger.warning("Черга Telegram-сповіщень переповнена - відкинуто: %s", label[:80])

    def _run(self) -> None:
        while True:
            job = self._queue.get()
            if job is None:
                return
            try:
                job()
            except Exception:
                logger.exception("Помилка фонової відправки в Telegram")

    def stop(self, timeout: float) -> None:
        """Дочекатись уже поставлених повідомлень (не довше timeout) і
        зупинити потік; без мережі решта черги губиться разом із
        процесом (потік - daemon)."""
        try:
            self._queue.put(None, timeout=1)
        except queue.Full:
            pass
        self._thread.join(timeout)

    def is_alive(self) -> bool:
        return self._thread.is_alive()


class _Periodic:
    """Періодична задача циклу монітора: "якщо минув інтервал — виконати, не впавши, і запам'ятати момент".
    Замінила шість ручних копій у Watchdog.run_forever(); тепер усі задачі однаково захищені від
    винятків (watchdog, що помирає, гірший за такий, що логує й працює далі). - `action` шукається в
    момент виклику (lambda), бо тести підміняють атрибути; - `interval` — число або функція (конфіг
    читається щоразу); `None` — на кожній ітерації (задача має власний таймер); - `enabled` —
    функція-умова (напр. AUTO_BACKUP_ENABLED), перевіряється ДО годинника; - `last` стартує з 0.0: перше
    спрацювання одразу після старту.
    """

    def __init__(
        self,
        action: Callable[[], None],
        *,
        error: str,
        interval: Union[float, Callable[[], float], None],
        enabled: Optional[Callable[[], bool]] = None,
    ) -> None:
        self._action = action
        self._error = error
        self._interval = interval
        self._enabled = enabled
        self.last = 0.0

    def run_if_due(self) -> bool:
        """Виконує задачу, якщо пора. Повертає, чи виконувалась."""
        if self._enabled is not None and not self._enabled():
            return False
        if self._interval is not None:
            interval = self._interval() if callable(self._interval) else self._interval
            elapsed = time.time() - self.last
            # elapsed < 0: годинник стрибнув НАЗАД (ручна зміна часу, RTC, збій
            # NTP). Без цього задача мовчала б, поки годинник не "наздожене"
            # мітку з майбутнього (вимір: після зсуву на 2 год 6 з 7 задач).
            if not (elapsed > interval or elapsed < 0):     # NaN-інтервал: не виконується
                return False
        try:
            self._action()
        except Exception:
            logger.exception(self._error)
        if self._interval is not None:
            self.last = time.time()      # і після збою: повтор - через інтервал, не щоітерації
        return True


def _optimize_db() -> None:
    vacuumed = db.vacuum_and_analyze()
    logger.info("Періодична оптимізація БД: ANALYZE, VACUUM %s",
                "виконано" if vacuumed else "пропущено (вільних сторінок мало)")


def _auto_backup() -> None:
    services.perform_auto_backup()
    logger.info("Автоматичний backup виконано")


class Watchdog:
    # Скільки опитувань поспіль роутер має мовчати, щоб стан "Starlink
    # вимкнено" зафіксувався (~30 с при інтервалі 10 с). Короткі розриви
    # WiFi (на Pi користувача - щохвилини, ~0.5 с) інколи збігаються з
    # опитуванням; без гістерезису кожен такий збіг давав пару подій
    # starlink_offline/online у журналі (до ~100 на годину, симуляція).
    STARLINK_OFFLINE_CONFIRM_POLLS = 3

    def __init__(self) -> None:
        self.client = StarlinkClient()
        self.consecutive_failures = 0
        self.last_reboot_ts = 0.0
        self._obstruction_warned = False        # подія obstruction_warning лише на переході через поріг
        # Зменшення зносу SD: dish-зчитування накопичуються тут, а flush (insert_metrics_batch) одним
        # batch-INSERT іде раз на DISH_METRICS_BATCH_INTERVAL_SEC у run_forever() і при SIGTERM/SIGINT —
        # тож systemctl restart/update.sh не губить дані, лише справжнє раптове вимкнення живлення.
        self.metrics_buffer: list[dict[str, Any]] = []
        self.last_batch_flush_ts = time.time()
        # На відміну від last_reboot_ts (0.0 = дозволити reboot одразу), тут ініціалізуємо поточним
        # часом: інакше now - 0.0 — величезне число, і backup надсилався б у Telegram при КОЖНОМУ старті
        # сервісу; таймер має рахуватись від запуску.
        self.last_telegram_backup_sent_ts = time.time()
        # Час першої невдалої спроби в поточному безперервному ланцюжку
        # відмов - None, поки dish online. Використовується, щоб приглушити
        # Telegram-сповіщення про auto-reboot при тривалій (>15 хв, за
        # замовчуванням) відсутності WiFi Starlink - події й далі пишуться
        # в журнал дашборду, лише Telegram-звіти призупиняються.
        self.first_failure_ts: Optional[float] = None
        # Попередні значення для детекції змін стану оновлення/попереджень.
        # None означає "ще не бачили жодного online-статусу" - перший
        # реальний статус теж логуємо, якщо він не порожній/не IDLE-без-алертів.
        self.prev_update_state: Optional[str] = None
        self.prev_alerts: Optional[set[str]] = None
        self.prev_router_update_state: Optional[str] = None
        self.prev_router_alerts: Optional[set[str]] = None
        # Останній відомий dish_id - потрібен, щоб прив'язати опитування
        # роутера (окремий цикл, без власного dish_id у RouterInfo) до
        # того самого фізичного Mini в таблиці known_devices.
        self.last_known_dish_id: Optional[str] = None
        # Групування спаму reboot-сповіщень: якщо стається кілька
        # ребутів поспіль за короткий час (флап), кожен окремий
        # "🔁 перезавантажено" - спам. reboot_notify_ts - timestamps
        # уже надісланих reboot-сповіщень (не всіх спроб reboot, лише
        # тих, що дійшли до Telegram) за ковзне вікно.
        self.reboot_notify_ts: list[float] = []
        self.reboot_spam_muted = False
        self.muted_reboot_count = 0
        # Starlink вимкнено (ніч, відключення світла): dish недоступний І
        # роутер теж не відповідає. None - Starlink у мережі. Поки стан
        # активний, watchdog не шле марних reboot (команда йде тим самим
        # недоступним шляхом) і не пише рядок на кожне опитування.
        self.starlink_offline_since: Optional[float] = None
        self._router_down_polls = 0
        # (online, update_state) попереднього опитування - зміна скидає
        # буфер у БД одразу (див. poll_once)
        self._last_state_key: Optional[tuple[bool, str]] = None
        self._local_fault_reported = False
        # Фоновий відправник запускається лише в run_forever(); без нього
        # (прямі виклики, тести) _notify() надсилає синхронно, як раніше.
        self._sender: Optional[_BackgroundSender] = None
        # last_reboot_ts, для якого вже записано "Пропускаю авто-reboot" -
        # один рядок на вікно очікування замість рядка щоопитування.
        self._reboot_skip_logged_for: Optional[float] = None

    def _notify(self, text: str) -> None:
        """Telegram-сповіщення: у робочому циклі - у фонову чергу (цикл
        монітора не чекає на мережу), інакше - одразу."""
        if self._sender is not None:
            self._sender.submit(lambda: self._send_now(text), text)
        else:
            self._send_now(text)

    def _send_now(self, text: str) -> None:
        """Безпечна відправка Telegram-сповіщення - ніколи не кидає виняток."""
        try:
            ok, msg = telegram_notify.send_message(text)
            # Telegram не налаштований/вимкнений - очікувана ситуація, не
            # попередження. Рішення - за кодом стану, не за текстом (текст
            # тепер перекладається мовою інтерфейсу).
            if not ok and telegram_notify.config_problem() is None:
                logger.warning("Telegram сповіщення не надіслано: %s", msg)
        except Exception as e:
            logger.warning("Помилка відправки Telegram-сповіщення: %s", e)

    def _notifications_muted(self) -> bool:
        """True, якщо dish недоступний безперервно довше
        config.NOTIFICATIONS_MUTE_AFTER_SEC - Telegram-сповіщення про
        auto-reboot тимчасово призупиняються (журнал подій не зачіпається)."""
        if self.first_failure_ts is None:
            return False
        return (time.time() - self.first_failure_ts) >= config.NOTIFICATIONS_MUTE_AFTER_SEC

    def _notify_reboot(self, text: str) -> None:
        """Групування спаму reboot-сповіщень. На відміну від _notifications_muted() (приглушує одну тривалу
        відмову), це про ЧАСТОТУ: кілька коротких reboot-циклів поспіль (флап), кожен із яких проходить
        MIN_REBOOT_INTERVAL_SEC. Коли за REBOOT_SPAM_WINDOW_SEC назбиралось REBOOT_SPAM_THRESHOLD+ таких
        сповіщень — мовчки групуємо (без окремого повідомлення про початок) до затишшя, тоді надсилаємо
        підсумок (_check_reboot_spam_recovery).
        """
        now = time.time()
        self.reboot_notify_ts = [t for t in self.reboot_notify_ts if now - t < config.REBOOT_SPAM_WINDOW_SEC]
        self.reboot_notify_ts.append(now)

        if len(self.reboot_notify_ts) < config.REBOOT_SPAM_THRESHOLD:
            self._notify(text)
            return

        if not self.reboot_spam_muted:
            self.reboot_spam_muted = True
            self.muted_reboot_count = 1
        else:
            self.muted_reboot_count += 1

    def _check_reboot_spam_recovery(self) -> None:
        """Викликається щоцикл опитування - якщо reboot-флап (див.
        _notify_reboot) припинився (минуло REBOOT_SPAM_WINDOW_SEC без
        нового reboot-сповіщення), надсилає підсумок і скидає стан
        групування, повертаючись до звичайного індивідуального режиму."""
        if not self.reboot_spam_muted:
            return
        if not self.reboot_notify_ts:
            return
        if time.time() - self.reboot_notify_ts[-1] < config.REBOOT_SPAM_WINDOW_SEC:
            return
        total = self.muted_reboot_count
        self._notify(i18n.t("tg_reboot_spam_over", total=total))
        self.reboot_spam_muted = False
        self.muted_reboot_count = 0
        self.reboot_notify_ts = []

    def _enter_starlink_offline(self) -> None:
        """Dish недоступний, роутер теж - Starlink вимкнено або його WiFi
        немає. Одна подія на вхід у стан; збої dish не накопичуються в
        consecutive_failures (це не зависання тарілки), тож після
        увімкнення watchdog стартує з нуля."""
        if self.starlink_offline_since is None:
            self.starlink_offline_since = self.first_failure_ts or time.time()
            logger.info(
                "Starlink недоступний (роутер %s теж не відповідає) - авто-reboot призупинено до відновлення",
                self.client.router_addr,
            )
            db.insert_event("starlink_offline", "Starlink недоступний (роутер не відповідає) — авто-reboot призупинено", success=True)
        self.consecutive_failures = 0

    def _exit_starlink_offline(self) -> None:
        """Роутер знову відповідає. Подія в журнал завжди; Telegram - лише
        якщо Starlink був вимкнений довше NOTIFICATIONS_MUTE_AFTER_SEC
        (нічне вимкнення - так; хвилинне перезавантаження при оновленні
        прошивки - ні, воно й так має власні сповіщення)."""
        since = self.starlink_offline_since
        self.starlink_offline_since = None
        self.first_failure_ts = None
        if since is None:
            return
        duration = time.time() - since
        uk = i18n.translator("uk")
        logger.info("Starlink знову доступний (був недоступний %s)", format_duration(duration, uk))
        db.insert_event("starlink_online", f"Starlink знову доступний (був недоступний {format_duration(duration, uk)})", success=True)
        if duration >= config.NOTIFICATIONS_MUTE_AFTER_SEC:
            tr = i18n.translator()
            self._notify(tr("tg_starlink_back", duration=format_duration(duration, tr)))

    def flush_metrics_buffer(self) -> None:
        """Записує накопичені dish-зчитування одним batch-INSERT і
        очищає буфер. Викликається періодично з run_forever() (кожні
        DISH_METRICS_BATCH_INTERVAL_SEC) і додатково при отриманні
        SIGTERM/SIGINT (graceful shutdown), щоб звичайний systemctl
        restart/update.sh НЕ втрачав буферизовані дані."""
        if not self.metrics_buffer:
            return
        try:
            db.insert_metrics_batch(self.metrics_buffer)
        except Exception as e:
            # НІКОЛИ не кидає: викликається з трьох місць - періодично в
            # циклі (виняток звідти валив увесь процес монітора: при
            # заблокованій БД/повній SD зависла тарілка не перезавантажувалась
            # ніколи), при зміні стану й з обробника SIGTERM (виняток там
            # заважав би вийти, а в poll_once() його ковтав би except -
            # сервіс ігнорував би SIGTERM аж до SIGKILL). Буфер лишається;
            # повтор - через DISH_METRICS_BATCH_INTERVAL_SEC, не щоітерації.
            self.last_batch_flush_ts = time.time()
            dropped = max(0, len(self.metrics_buffer) - _METRICS_BUFFER_MAX)
            if dropped:
                del self.metrics_buffer[:dropped]   # найстаріші: пам'ять не росте безмежно
            logger.warning("Не вдалося записати %d метрик у БД (повтор через %d с%s): %s",
                           len(self.metrics_buffer), config.DISH_METRICS_BATCH_INTERVAL_SEC,
                           f", відкинуто {dropped} найстаріших" if dropped else "", e)
            return
        self.metrics_buffer = []
        self.last_batch_flush_ts = time.time()

    def _report_local_fault(self, status: DishStatus) -> None:
        """Один раз за процес (усунення потребує перезапуску сервісу - модуль
        завантажується при старті): подія в журналі, лог, Telegram."""
        if self._local_fault_reported:
            return
        self._local_fault_reported = True
        logger.error("Локальна несправність моніторингу тарілки: %s. Перезавантаження тарілки вимкнено.", status.error)
        self._event("local_fault", f"Моніторинг тарілки не працює (локальна причина): {status.error}. "
                                    "Перезавантаження тарілки вимкнено", success=False)
        self._notify(i18n.t("tg_local_fault", error=status.error))

    def poll_once(self) -> DishStatus:
        self._check_reboot_spam_recovery()
        status = self.client.get_status()
        self.metrics_buffer.append(status.to_dict())
        # Метрики пишуться пакетом раз на DISH_METRICS_BATCH_INTERVAL_SEC (менше записів на SD), але
        # дашборд і дисплей читають БД, тож новий стан (online/offline, оновлення прошивки, заміна
        # Starlink) з'являвся б із затримкою до 30 с. Зміна стану рідкісна — скидаємо одразу, однакові
        # опитування й далі йдуть пакетом. Збій запису лише логується: недоступна БД (заблокована, повна
        # SD) не має обривати опитування, інакше watchdog нижче не дійшов би до лічильника збоїв і
        # перезавантаження зависшої тарілки. Буфер лишається для планового запису.
        state_key = (status.online, status.update_state)
        changed = self._last_state_key is not None and state_key != self._last_state_key
        self._last_state_key = state_key
        if changed:
            self.flush_metrics_buffer()   # не кидає: збій лише логується, буфер лишається

        if status.local_fault:
            # Локальна несправність (модуль starlink_grpc не завантажився) - не збій
            # тарілки: не рахуємо, не перезавантажуємо, повідомляємо один раз.
            self._report_local_fault(status)
            return status
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

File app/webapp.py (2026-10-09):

"""Flask веб-інтерфейс: дашборд статусу Starlink, журнал подій, ручний reboot."""
import logging
import math
import os
import re
import time
from typing import Any, Callable, Optional
from urllib.parse import urlparse

from flask import Flask, jsonify, render_template, request
from flask.json.provider import DefaultJSONProvider
from flask.typing import ResponseReturnValue

from app import config, config_editor, db, i18n, log_redact, pi_power, services, telegram_notify
from app.starlink_client import StarlinkClient

logging.basicConfig(level=logging.INFO)
log_redact.install()   # токен бота ніколи не потрапляє в журнал (див. app/log_redact.py)


class _QuietSuccessfulGets(logging.Filter):
    """Werkzeug пише рядок на КОЖЕН запит, а дашборд опитує сервер ~3500 разів/год на вкладку (~83 000
    рядків ≈ 8 МБ/добу на SD). Відкидаємо лише успішні GET (опитування, статика); POST-дії (з IP
    джерела: єдиний слід дій без автентифікації) і помилки 4xx/5xx лишаються.
    """
    _SUCCESSFUL_GET = re.compile(r'"GET [^"]*" [23]\d\d ')

    def filter(self, record: logging.LogRecord) -> bool:
        return not self._SUCCESSFUL_GET.search(record.getMessage())


logging.getLogger("werkzeug").addFilter(_QuietSuccessfulGets())
logger = logging.getLogger("webapp")

app = Flask(__name__, template_folder="../templates", static_folder="../static")
# Обмеження тіла запиту: Flask за замовчуванням його не має, а /api/settings-restore
# читає JSON цілком у пам'ять (Pi Zero - 415 МБ). Реальний бекап станції з 233
# пристроями - ~42 КБ; 5 МБ - запас понад 100 разів. Перевищення -> HTTP 413.
app.config["MAX_CONTENT_LENGTH"] = 5 * 1024 * 1024
# Кешування статики (dashboard.js, logo.png) на стороні браузера - зменшує
# кількість запитів при кожному відкритті/перезавантаженні дашборду,
# помітно на слабкому WiFi-каналі Pi Zero 2 W. API-ендпоінти (динамічні
# дані) цього не стосуються - кешується лише /static/*.
app.config["SEND_FILE_MAX_AGE_DEFAULT"] = 3600
client = StarlinkClient()

_STATIC_DIR = os.path.join(os.path.dirname(__file__), "..", "static")


def _static_v(filename: str) -> str:
    """URL статичного файлу з ?v=<mtime> (cache-busting): після update.sh файл змінюється, URL змінюється
    разом із ним, і браузер одразу бере свіжу версію, а не чекає SEND_FILE_MAX_AGE_DEFAULT=3600 с чи
    ручного hard refresh.
    """
    path = os.path.join(_STATIC_DIR, filename)
    try:
        v = int(os.path.getmtime(path))
    except OSError:
        v = 0
    return f"/static/{filename}?v={v}"


app.jinja_env.globals["static_v"] = _static_v


# window.I18N вбудовується в КОЖНУ сторінку: раніше всі 366 ключів (~58 КБ із ~66 КБ сторінки), хоча JS
# використовує ~121. Набір визначається при старті скануванням t('...') у static/*.js (виклики лише з
# літералами: гарантує test_js_i18n_calls_are_static_literals, інакше динамічний ключ тихо випав би).
_JS_T_CALL_RE = re.compile(r"(?<![\w.])t\(\s*['\"](\w+)['\"]")


def _collect_js_i18n_keys(static_dir: str) -> frozenset[str]:
    keys: set[str] = set()
    for name in os.listdir(static_dir):
        if name.endswith(".js"):
            with open(os.path.join(static_dir, name), encoding="utf-8") as f:
                keys.update(_JS_T_CALL_RE.findall(f.read()))
    return frozenset(keys)


_JS_I18N_KEYS = _collect_js_i18n_keys(app.static_folder or "static")

# UTF-8 замість \uXXXX для кирилиці: 2 байти на літеру замість 6 -
# і в window.I18N, і в JSON-відповідях API. Безпека вбудовування в
# <script> не залежить від цього: tojson окремо екранує < > & '.


def _scrub_non_finite(value: Any) -> Any:
    """float inf/-inf/NaN -> None рекурсивно (див. db._finite)."""
    if isinstance(value, float):
        return value if math.isfinite(value) else None
    if isinstance(value, dict):
        return {k: _scrub_non_finite(v) for k, v in value.items()}
    if isinstance(value, (list, tuple)):
        return [_scrub_non_finite(v) for v in value]
    return value


class _FiniteJSONProvider(DefaultJSONProvider):
    """Flask за замовчуванням віддає inf як `Infinity`, а NaN як `NaN` - це
    НЕвалідний JSON, `JSON.parse` у браузері падає, і дашборд переставав
    оновлювати статус. Будь-яке нескінченне значення (навіть уже збережене в
    БД до виправлення в db._finite) віддається як null."""

    def dumps(self, obj: Any, **kwargs: Any) -> str:
        return super().dumps(_scrub_non_finite(obj), **kwargs)


@app.before_request
def _reject_cross_site_posts() -> Any:
    """Захист від CSRF. Автентифікації немає (рішення власника: довірена LAN), але сторінка з будь-якого
    сайту у браузері комп'ютера LAN могла б надіслати "просту" міжсайтову форму (text/plain, без
    прелайту) на /api/system-shutdown чи /api/system-reboot й вимкнути станцію разом з інтернетом
    (виміряно: усі POST виконувались). Браузер сам виставляє Origin і Sec-Fetch-Site (скрипт сторінки їх
    не підробить); curl/скрипти без заголовків працюють як раніше. Від DNS-rebinding не захищає (запит
    тоді "same-origin" з чужого імені).
    """
    if request.method != "POST":
        return None
    fetch_site = request.headers.get("Sec-Fetch-Site")
    origin = request.headers.get("Origin")
    cross_site = fetch_site is not None and fetch_site not in ("same-origin", "none")
    if origin is not None and not cross_site:
        cross_site = urlparse(origin).netloc != request.host            # "null" (opaque origin) -> порожній netloc -> блок
    if cross_site:
        return jsonify({"success": False, "error": i18n.t("cross_site_blocked")}), 403
    return None


_json_provider = _FiniteJSONProvider(app)
_json_provider.ensure_ascii = False
app.json = _json_provider


@app.context_processor
def _inject_i18n() -> dict[str, Any]:
    """t()/ui_lang/i18n_json для шаблонів - усі три з ОДНОГО читання
    мови з БД на рендер. Раніше глобальний i18n.t читав мову на кожен
    {{ t('key') }} (~55 SQLite-з'єднань на рендер головної сторінки,
    виміряно); тепер - одне."""
    lang = i18n.get_language()
    return {
        "t": i18n.translator(lang),
        "ui_lang": lang,
        "i18n_json": i18n.all_translations_for_current_lang(lang, _JS_I18N_KEYS),
    }


def _json_body() -> dict[str, Any]:
    """Тіло запиту як JSON-об'єкт. Відсутнє/некоректне тіло або валідний
    JSON, що НЕ є об'єктом ([1,2], "str", 123) -> {}. Раніше обробники
    брали get_json() і далі payload.get(...) - на не-об'єктному JSON це
    давало 500 з трейсбеком (знайдено фазингом ендпоінтів)."""
    try:
        data = request.get_json(silent=True)
        return _scrub(data) if isinstance(data, dict) else {}
    except RecursionError:      # json.loads / _scrub на вкладеності в тисячі рівнів: інакше 500 із трейсбеком
        return {}
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

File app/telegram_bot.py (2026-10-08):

"""
Вхідні команди Telegram-бота: long polling (без webhook), працює в
потоці starlink-monitor.service. Авторизація за chat_id зі списку
отримувачів сповіщень (app/telegram_notify).

Команди: /status, /checkupdates, /reboot (з підтвердженням),
/id [dish_id], /help.
"""
import html
import logging
import math
import threading
import time
from concurrent.futures import ThreadPoolExecutor
from typing import Any, Callable, Optional

import requests

from app import config, db, i18n, services, telegram_notify
from app import labels
from app.log_redact import redact
from app.starlink_client import StarlinkClient

logger = logging.getLogger("telegram_bot")

# Паузи циклу опитування бота, с
_DISABLED_RECHECK_SEC = 10     # бот вимкнений/не налаштований - як часто перевіряти налаштування
_LOOP_ERROR_PAUSE_SEC = 5      # після неочікуваної помилки в циклі
_POLL_ERROR_PAUSE_SEC = 3      # після невдалого getUpdates (мережа, відмова API)

API_BASE = "https://api.telegram.org/bot{token}/{method}"

# Скільки секунд діє запит підтвердження /reboot, перш ніж вважати його
# застарілим (захист від випадкового підтвердження старого запиту)
def _api_call(
    method: str, token: str, http_timeout: float, *, session: Optional[requests.Session] = None, **params: Any,
) -> Optional[dict[str, Any]]:
    """Викликає Telegram Bot API; повертає розпарсений JSON або None при мережевій помилці. Telegram
    повертає ВАЛІДНИЙ JSON і для відхилених запитів (`{"ok": false, "description": "message is too
    long"}` — понад 4096 символів чи невалідний HTML), тому `ok` перевіряється явно: інакше помилка
    мовчки ігнорується й виглядає як "команда не відповідає" (так /id без аргументів перевищував ліміт
    при багатьох тарілках).
    """
    try:
        resp = telegram_notify._request_with_eth0_fallback(
            "post",
            API_BASE.format(token=token, method=method),
            json=params,
            timeout=http_timeout,
            session=session,
        )
        data: dict[str, Any] = resp.json()
        if not data.get("ok"):
            logger.warning(
                "Telegram API %s відхилив запит: %s (chat_id=%s)",
                method, data.get("description", "невідома причина"), params.get("chat_id", "?"),
            )
        return data
    except requests.RequestException as e:
        logger.warning("Telegram API виклик %s провалився: %s", method, redact(str(e), token))
        return None


def _shown_router_state(state: str) -> str:
    """Тимчасові хмарні помилки показуються як "немає оновлень" - так
    само, як на дашборді й TFT-дисплеї (спільний список у labels.py)."""
    return "NOT_RUN" if state in labels.ROUTER_STATES_SHOWN_AS_NO_UPDATES else state


def _router_state_label(state: str) -> str:
    return labels.router_update_state_label(_shown_router_state(state))


def _progress_suffix(pct: Any) -> str:
    """" (42%)" - відсоток оновлення; нічого, якщо його немає, він нульовий чи не скінченний
    (раніше друкувалось "(nan%)", "(inf%)", "(-5%)", "(150%)"). Поза 0..100 обрізається - так
    само, як прогрес-бар на дисплеї."""
    if not isinstance(pct, (int, float)) or isinstance(pct, bool) or not math.isfinite(pct):
        return ""
    clamped = max(0.0, min(100.0, float(pct)))
    return f" ({clamped:.0f}%)" if clamped else ""


def _update_lines(
    status: Any, *, online_key: str, offline_key: str, state_label: Callable[[str], str], with_alerts: bool,
) -> list[str]:
    """Рядки про dish або роутер для /status і /checkupdates. Раніше цей блок був
    скопійований чотири рази (два компоненти x дві команди, 77% подібності);
    різниці між командами - лише ключ рядка "онлайн" і кількість попереджень."""
    if not status.online:
        return [i18n.t(offline_key, error=labels.short_error(status.error) or i18n.t("no_response"))]
    label = state_label(status.update_state) if status.update_state else i18n.t("not_available_short")
    lines = [
        i18n.t(online_key, sw=status.software_version or "?"),
        i18n.t("tg_update_line", label=label) + _progress_suffix(status.update_progress_pct),
    ]
    if with_alerts and status.active_alerts:
        lines.append(i18n.t("tg_alerts_count_line", n=len(status.active_alerts)))
    return lines


def _obj(value: Any) -> dict[str, Any]:
    """Словник або {}: `.get("chat", {})` не рятує, коли ключ є зі
    значенням None - тоді наступний .get() падав AttributeError."""
    return value if isinstance(value, dict) else {}
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

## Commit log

2026-07-25 add SPI screen
2026-07-25 гзвфеу
    [starlink_monitor_case.FCStd, starlink_monitor_case.stl, starlink_monitor_cover_DISPLAY.FCStd]

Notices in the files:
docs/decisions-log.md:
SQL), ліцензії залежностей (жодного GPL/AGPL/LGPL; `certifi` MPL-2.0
